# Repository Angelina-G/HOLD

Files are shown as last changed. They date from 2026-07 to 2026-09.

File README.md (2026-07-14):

# HOLD 工程仓库

## 项目简介
本仓库用于承载 HOLD 项目的嵌入式固件实验、整机联调、小程序前端壳子与阶段性开发记录。

当前重点包括：
- XIAO ESP32S3 多传感器固件验证
- MAX30102、MPU6050/MPU6500、压力模块、DRV2605L 的独立探针与整机冒烟测试
- 呼吸/心率相关原始数据采集与日志导出
- 微信小程序调试页与用户页壳子
- 接线文档、开发日志和阶段性方案沉淀

## 当前工程结构
- 固件主工程：PlatformIO + Arduino，板卡以 `seeed_xiao_esp32s3` 为主
- 传感器与算法公共头文件：`include/`
- 各独立实验入口与整机测试入口：`src/`
- 接线文档与方案说明：`docs/`
- 开发日志与阶段记录：`log/`
- 小程序与云函数：`web/`
- 串口采集与辅助脚本：`tools/`

## 当前实现范围
- 独立环境：MPU6050/MPU6500 探针、单 IMU 呼吸实验、MAX30102 指尖/胸口环境、DRV2605L LRA 环境、BLE 按键链路环境
- 整机环境：IMU + PPG + 压力 + DRV2605L + 热反馈 PWM + RGB 流水灯的统一冒烟测试
- 诊断能力：I2C 地址可见性、启动阶段日志、RGB 单色自检、兼容 `MPU6500/MPU9250` 系列 IMU 识别

## MR60BHA2 当前建议
- XIAO ESP32C6 + MR60BHA2 的首轮验证暂时改走 Arduino IDE 独立草图路径，避免继续受 PlatformIO 的 ESP32-C6 Arduino 环境问题阻塞。
- 可直接使用 [arduino/README.md](c:\Users\LBG\Desktop\hold\arduino\README.md) 中的验证步骤与草图。

## 推荐使用方式
1. 在 HOLD 根目录执行 pio run 进行编译。
2. 连接开发板后执行 pio run -t upload 进行烧录。
3. 执行 pio device monitor -b 115200 查看串口日志。

## 串口日志预期
- 上电或复位后会先输出一组启动信息。
- 随后每次 LED 翻转都会输出一行日志，包含运行毫秒数和当前 LED 状态。
- 如果打开监视器时没有看到启动日志，按一下开发板 Reset 键即可重新看到完整启动过程。

## 烧录异常排查
- 如果串口口号未出现，先更换数据线并重新插拔开发板。
- 如果上传失败，可按住 BOOT 键接入 USB 进入 BootLoader 模式后重新烧录。
- 如果点灯逻辑与观察结果相反，优先检查是否误用了外接 LED，而不是板载用户灯。

## 待确认项
- 当前仓库开发指南提到 Plus 版本，但本工程先按通用 XIAO ESP32S3 板卡配置建立。
- 若你的实际硬件为 XIAO ESP32S3 Plus，后续建议补充 Flash 容量与分区配置验证。

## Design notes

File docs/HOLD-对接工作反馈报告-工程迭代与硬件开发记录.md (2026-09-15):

# HOLD 对接工作反馈报告：工程迭代记录与硬件开发记录

## 摘要

本文档面向 HOLD 项目阶段性交接、科研汇报与后续工程复盘，整理 2026-05-22 至 2026-07-11 期间的主要 memory、debug、反馈、收获经验、疑难问题与可探索优化点。资料来源主要为仓库内 `log/`、`docs/`、`captures/` 与集成快照记录。

项目整体演进路线可以概括为：先完成 XIAO ESP32S3 主控与单传感器最小读数链路，再进入多传感器整机冒烟测试，随后打通 BLE 与微信小程序的用户侧控制闭环。硬件路线从 MAX30102、ICS43434、AD8232、薄膜压力、MPU6050/MPU6500、DRV2605L/LRA 与柔性热反馈等模块逐步展开，软件路线则围绕 PlatformIO 固件环境、串口诊断、VOFA 可视化、小程序 BLE 协议和数据闭环持续迭代。

当前阶段最重要的工程结论是：项目已具备多模块最小可运行能力和端到端 BLE 通信基础，但距离稳定、长期、可穿戴级产品仍有三类核心问题需要继续研究：生理信号质量与佩戴结构耦合、呼吸/心率算法的个体化稳健性、热/振动反馈的安全闭环与体感标定。

## 资料来源

本报告依据以下项目内记录归纳：

| 类别 | 代表文件 | 用途 |
|---|---|---|
| 主控与固件基础 | `log/firmware/2026-05-22-xiaoESP32S3点灯测试.md` | 验证主控烧录、串口、LED 心跳 |
| PPG | `log/max30102/raw-read/2026-05-23-MAX30102原始读取接入.md` | MAX30102 原始 Red/IR、FIFO、BPM 排查 |
| 麦克风 | `log/ics43434/raw-read/2026-05-25-ICS43434最小读取接入.md` | ICS43434 I2S 最小读取 |
| ECG | `log/ad8232/raw-read/2026-05-25-AD8232最小读取接入.md` | AD8232 模拟 ECG 最小链路 |
| 压力 | `log/pressure-film/raw-read/2026-05-25-薄膜压力模块最小读取接入.md` | 薄膜压力 AO 到 ADC 与 0-10 量化 |
| 传感路线 | `log/dev/2026-05-26/sensor-strategy/阶段性传感路线决策.md` | ECG、PPG、毫米波、位点策略 |
| ECG 布局 | `log/dev/2026-05-28/sensor-strategy/2026-05-28-近期传感与ECG布局讨论记录.md` | 胸带 ECG、三电极与两电极关系 |
| IMU 呼吸 | `log/firmware/2026-06-08-单IMU呼吸与运动状态实验.md` | 单 IMU 呼吸识别、个体化校准、VOFA 调试 |
| 触觉反馈 | `log/firmware/2026-06-11-DRV2605L独立LRA深呼吸震动环境.md` | DRV2605L + LRA RTP 呼吸包络 |
| 接线方案 | `docs/2026-06-18-完整小demo接线表.md` | 完整 Demo 引脚、总线、风险 |
| 整机测试 | `log/integration/2026-06-28-整机冒烟测试环境.md` | IMU、PPG、压力、DRV、热反馈、RGB 联调 |
| BLE 闭环 | `log/integration/2026-07-11-HOLD-integrated-BLE-miniapp-link.md` | BLE 通知、命令、小程序控制路径 |
| 小程序功能 | `docs/HOLD-miniapp-function-list.md` | 用户侧功能与调试页定位 |

## 一、项目阶段性脉络

### 1. 起步阶段：主控与最小反馈链路

项目初期采用 XIAO ESP32S3 / ESP32S3 Plus 作为主控平台，使用 PlatformIO + Arduino 进行固件开发。早期工作重点不是复杂算法，而是确认最小硬件链路：

- 主控可正常编译、烧录、复位。
- 串口日志可稳定输出。
- 板载 LED 或外接 LED 可作为运行心跳和阶段报码。
- 后续每个传感模块均以独立 reader 或独立 env 方式接入，避免在主循环中堆叠未验证逻辑。

这一阶段形成的经验是：嵌入式原型开发必须先确认“板子活着、串口活着、日志可见”，否则后续传感器问题会与供电、串口、烧录、引脚冲突混在一起。

### 2. 单传感器 bring-up 阶段

2026-05-23 至 2026-05-25 期间，项目依次完成 MAX30102、ICS43434、AD8232 与薄膜压力模块的最小接入。

此阶段采用的通用方法是：

- 每个模块先独立建立可观察输出。
- 先证明“能读到原始数据”，再考虑算法。
- 为初始化、寄存器访问、采样窗口、串口状态保留足够诊断字段。
- 对模拟输入先做窗口统计或量化，不直接进入复杂识别。

该策略有效避免了在硬件不确定时过早引入算法复杂度。

### 3. 传感路线收敛阶段

2026-05-26 至 2026-05-28 的路线评审将项目从“所有传感器等权推进”收敛为“ECG 主路线 + PPG/OHR 备路线 + 麦克风/压力辅助 + 毫米波中长期探索”。

关键判断包括：

- MAX30102 已证明 PPG 采样与基础 BPM 能力，但它更像手指/近指夹验证，不宜直接推演为后颈或挂颈式最终方案。
- AD8232 更适合作为当前 MVP 的节律主链路，因为 ECG 对 beat-to-beat、R-R、HRV 的工程价值更直接。
- 胸带 ECG 的难点主要在结构贴合、预紧、防滑和电极材料，而不是单纯“有没有第三个参考点”。
- 毫米波可作为呼吸、体动、存在感知的辅助或中长期路线，不宜直接替代 ECG 做 HRV 主链路。

### 4. 单 IMU 呼吸识别阶段

2026-06-06 至 2026-06-09，项目围绕 MPU6050/MPU6500 进行了单 IMU 胸口呼吸检测实验。该阶段是 debug 最密集的部分之一。

工程路线经历了多次转向：

1. 原始探针：确认 I2C 地址、WHO_AM_I、accel/gyro 可读。
2. 固定阈值呼吸识别：从重力投影、峰谷检测、运动门控开始。
3. 状态机排查：通过 `detected_peaks`、`detected_troughs`、`accepted_cycles`、`last_reject` 等诊断字段定位失败原因。
4. 个体化校准：从继续调固定阈值转向“引导式校准 + 个人参数”。
5. VOFA 可视化：输出呼吸载波、基线、滤波、斜率、阈值、拒绝原因等通道，直观看清波形。
6. 二级低通与最小反转摆幅：抑制高频毛刺导致的一口多记。

该阶段的核心经验是：当真实人体佩戴带来强个体差异时，继续堆全局阈值会陷入“漏检”和“误检”的反复摆动；更稳的路线是建立个人校准和可视化诊断。

### 5. 反馈器件与整机 Demo 阶段

2026-06-11 后，项目新增 DRV2605L + LRA 独立震动环境，并在 2026-06-18 形成完整小 Demo 接线表。2026-06-28 进一步形成整机冒烟测试环境，把 IMU、PPG、压力、DRV2605L、热反馈 PWM 和 RGB 状态灯整合到同一入口。

重要策略包括：

- IMU 与 PPG 共用主 I2C：D4(GPIO5) / D5(GPIO6)。
- DRV2605L 单独使用副 I2C：D6(GPIO43) / D7(GPIO44)。
- 压力模块 AO 接 D0/A0(GPIO1)，DO 暂不接。
- RGB 使用 D8/D9/D10，并保留板载 GPIO21 作系统状态。
- 热反馈只输出 MOSFET Gate 控制 PWM，不允许 GPIO 直接驱动加热片。

整机阶段发现并修复了一个典型嵌入式问题：`Serial.printf` 参数错位导致 Guru Meditation 崩溃。该问题表现为启动阶段似乎成功，但进入运行状态打印后重启。经验是，串口日志本身也可能成为崩溃源，格式化字符串必须与参数严格一致。

### 6. BLE 与小程序闭环阶段

2026-07-11，项目重点转向“硬件已连接但小程序无数据”“呼吸反馈命令无硬件响应”“校准无可见状态变化”等端到端问题。

最终形成的 BLE 闭环包括：

- 固件广播稳定 BLE 服务 `HOLD-INTEGRATED`。
- notify characteristic 带 BLE2902/CCCD。
- command characteristic 支持 write / write-no-response。
- 固件每 500ms 发 compact JSON telemetry。
- 小程序集中管理 UUID、解析 JSON/key-value/binary fallback。
- 首页成为用户控制面，调试页保留原始包和十六进制诊断。
- 命令覆盖 `breath_start`、`breath_stop`、`calibrate_start`，并能驱动 DRV2605 与状态字段变化。

此阶段的关键收获是：BLE 问题不能只看“是否连接成功”。完整链路必须同时满足服务发现、通知订阅、包格式可解析、命令写入、固件执行与状态回传。

## 二、工程迭代记录

### 1. 平台与工程组织迭代

项目采用 PlatformIO 多环境组织方式。每个独立实验入口均通过独立 env 或独立 `src/` 子目录隔离：

- `mpu6050_xiao_esp32s3_probe`
- `mpu6050_xiao_esp32s3_respiration`
- `drv2605l_xiao_esp32s3_lra_breath`
- `xiao_esp32s3_full_smoke_test`
- MAX30102 VOFA 与 BLE 按钮链路相关环境

这种组织方式的优点是：

- 单模块验证不干扰主线固件。
- 整机联调前可以保留独立回归入口。
- 同一硬件模块在不同阶段的引脚口径可以被明确记录。
- 出问题时可以回退到更小的验证环境。

需要注意的是，独立环境过多也会带来“接线口径分裂”。因此后续应维持一份唯一的整机引脚分配表，并明确哪些引脚只是独立实验临时口径。

### 2. 串口日志与诊断口径迭代

项目早期大量依赖串口日志完成 bring-up。日志从简单心跳逐步扩展为：

- I2C 扫描和地址可见性。
- 初始化阶段 `ok/miss/reason`。
- FIFO 指针、寄存器回读、错误计数。
- 传感器窗口统计。
- 呼吸状态机拒绝原因。
- VOFA 纯数值流。
- 整机状态单行汇总。
- BLE telemetry JSON。

这一过程表明，嵌入式项目中的“debug 输出”本身是工程资产，而不是临时噪声。它帮助团队从“感觉没反应”转向“知道卡在哪一层”。

### 3. 小程序工程迭代

小程序侧经历了从调试页、页面壳、首页控制面到 BLE 协议统一的过程。关键迭代点包括：

- 清理 sitemap 提示，避免开发者工具噪音干扰判断。
- 将首页定位为真实用户控制面。
- 将 debug 页定位为协议诊断面。
- 建立 `web/utils/ble-protocol.js`，统一 UUID、解析、字段归一化和中文标签。
- 支持原始通知包、解析后 metrics、连接状态、校准状态、呼吸引导状态展示。

经验是：用户界面和调试界面需要分层。把所有诊断内容塞进用户首页，会降低交互清晰度；但完全隐藏原始包，又会降低联调效率。

### 4. 数据导出与可视化迭代

项目在 IMU 呼吸和 MAX30102 阶段均使用 VOFA 或 CSV 作为关键观察工具：

- MPU6050 呼吸输出 23 列原始轴、滤波信号、状态机字段。
- MAX30102 手指/胸口实验输出 Red/IR、接触、滤波、幅值等字段。
- VOFA 用于确认“是否有主波”“毛刺在哪”“阈值是否与波形同量级”。

这说明当前项目已经从纯串口文本调试转向半结构化实验数据采集。后续若要偏科研，应进一步统一数据格式、实验标签、佩戴位点、动作条件与样本编号。

## 三、硬件开发记录

### 1. XIAO ESP32S3 主控

主控承担多传感器采样、反馈控制、BLE 广播与命令处理。已验证内容包括：

- PlatformIO 编译与烧录。
- USB 串口监视。
- 板载 LED 心跳。
- 多 I2C 与 ADC 混合使用。
- BLE 服务、通知与命令通道。

疑难点：

- 串口工具占用 COM 口会导致上传失败。
- ESP32S3 启动脚和板载 LED 逻辑需要避免误用。
- 整机联调时，日志格式错误可直接导致运行期崩溃。

### 2. MAX30102 PPG

开发目标从“能读到 Red/IR 原始值”逐步推进到“简单 BPM 与接触质量判断”。

主要成果：

- I2C 地址 0x57 和 Part ID 校验。
- FIFO 指针、配置寄存器、slot 配置与 rollover 诊断。
- 连续 Red/IR 原始样本输出。
- 基于 IR 的轻量心率估计。
- 窗口均值触点判断与 PBA 风格峰值检测。

主要 debug 记录：

- 初期出现 `part-id-read-failed`、`part_id=0x0`，需要 I2C 扫描和周期重扫。
- 后续出现 `reason=ok` 但 `wr_ptr=0 | rd_ptr=0 | avail=0`，说明通信成功但 FIFO 未产样本。
- 加入 slot 配置与关键寄存器回读后，FIFO 开始累计样本。
- `beats=0` 更像算法阈值和状态机问题，而不是硬件完全失效。
- 2Hz 串口输出只是显示频率，不等于传感器采样频率。

经验：

- PPG 调试不能只看设备识别，要同时看 FIFO 是否滚动、配置是否回读成功、接触均值是否稳定。
- 单点接触判断不可靠，窗口均值更稳。
- 从手指到胸口或其他位点时，PPG 的光机结构和贴合压力会显著改变信号质量。

### 3. ICS43434 数字麦克风

开发目标为 I2S 最小读取链路。

主要成果：

- 新增 I2S 引脚、采样率、DMA、批处理配置。
- 每 10ms 尝试读取样本批次，每 500ms 输出窗口统计。
- 输出 `min/max/p2p/mean` 等能量级字段。
- 实机确认 `seq`、`p2p`、`mean` 持续变化。

疑难点：

- 曾出现 `main.cpp` 被旧版本逻辑覆盖导致看不到麦克风信息。
- 第三方串口工具可能出现显示会话异常，PlatformIO 监视器确认固件实际输出。
- 声道选择、I2S 引脚丝印差异会造成数值异常弱或空读。

经验：

- 音频模块第一阶段只证明“有样本、有能量变化”即可，不应提前扩展声源识别。
- 若后续要做声音事件，应单独规划窗口、阈值、频域特征和隐私边界。

### 4. AD8232 ECG

开发目标为 OUTPUT 模拟量到 ADC 的最小链路，并为后续 R 峰和 HRV 做准备。

主要成果：

- OUTPUT 接 D1/A1/GPIO2。
- ADC 约 250Hz 轮询。
- 串口输出原始值和窗口统计。
- 支持 VOFA 单列原始 ADC 输出。
- 实机确认 raw/mean/max/p2p 持续变化。

疑难点：

- 当前读到变化不等于高质量 ECG。
- 多次出现 `min=0`，可能对应未贴附、接触不良、偏置不稳或噪声较大。
- LO+ / LO- 尚未纳入导联脱落判断。

经验：

- ECG 主线的真正难点在佩戴结构、电极接触和运动伪差。
- 凝胶电极适合作为研发基准件，不宜直接视为最终消费产品方案。
- 两电极适合产品化胸带，三电极更适合研发阶段稳定前端。

### 5. 薄膜压力模块

开发目标为 AO 模拟量读取并映射为 0-10 相对等级。

主要成果：

- AO 接 D0/A0/GPIO1。
- 启动时采集静置基线。
- 少量 ADC 采样平均后输出相对压力等级。
- 串口输出 `[pressure] N`，便于肉眼判断。

疑难点：

- 实机初期多为 `[pressure] 0`，更可能是未按压或模块未接入 AO，不代表代码失效。
- 不同模块 AO 动态范围可能不同，需要保留最小量程参数。

经验：

- 压力模块本阶段只使用 AO；DO 是比较器二值输出，不适合表达连续压力。
- 启动基线采集能避免空载偏置直接映射为非零等级。

### 6. MPU6050 / MPU6500 IMU

开发目标包括原始姿态/运动读取、呼吸节律估计和运动门控。

主要成果：

- I2C 探针确认模块在线。
- 兼容 MPU6050、MPU6500、MPU9250/9255 常见 WHO_AM_I。
- 输出加速度、角速度、pitch/roll、运动等级。
- 建立单 IMU 呼吸状态机和个体化校准。
- 接入 VOFA 调试流。

疑难点：

- 初期呼吸字段长期 `n/a`，原因不是完全无数据，而是重力投影和阈值过保守。
- 峰值计数快速增长而谷值不增长，说明状态机被高频扰动刷新。
- 时间窗过紧会让有效周期归零，过松又会导致一口多记。
- 累计平均周期显示会让用户误以为板载时钟不准。
- 校准阶段若只记录原始轴范围，会被姿态漂移拉高阈值。

经验：

- 呼吸识别必须区分“有没有主波”和“状态机是否正确接受主波”。
- 固定阈值难以覆盖不同佩戴方式和个体呼吸差异。
- 需要把运行期判定量与校准期学习量保持同一量纲。
- VOFA 曲线对定位高频毛刺、阈值失真和过早触发非常关键。

### 7. DRV2605L + LRA 震动反馈

开发目标为深呼吸式触觉引导。

主要成果：

- 独立 env 初始化 DRV2605L。
- 使用 LRA + RTP 实时播放模式。
- 输出吸气/呼气强到弱包络。
- 副 I2C D6/D7 独立于传感主总线。
- BLE 阶段命令可驱动 DRV2605 状态变化。

疑难点：

- 尚未根据具体 LRA 型号设置 rated voltage、overdrive clamp 和 auto-calibration。
- 体感强度、颗粒感、吸呼分辨度仍需人体确认。
- 震动可能通过机械耦合影响 PPG 或 IMU 信号。

经验：

- 触觉反馈应先独立验证体感，不要一开始并入传感状态机。
- DRV2605L 使用 RTP 更适合长呼吸节律包络，内置 ROM 效果更适合短脉冲。

### 8. 柔性热反馈

开发目标为热反馈控制脚与安全边界定义。

主要成果：

- 文档中补充柔性电加热片/发热膜。
- 整机冒烟环境中加入热反馈 PWM 控制脚。
- 上电先拉低，延迟 5 秒后再输出 80% PWM，便于观察启动阶段。
- 明确必须使用逻辑级 N-MOSFET 控制外部电源。

疑难点：

- 当前缺少加热片额定参数。
- 尚未建立温度采样、限温保护、安全时长和热舒适度闭环。

经验：

- GPIO 不能直接驱动加热片。
- 开环 PWM 只能作为控制脚验证，不宜作为长期功能。

### 9. RGB 状态灯

开发目标为整机阶段可视化状态反馈。

主要成果：

- RGB 共阴极接 D8/D9/D10。
- 启动阶段加入 R/G/B 单色自检。
- 板载 GPIO21 保留为系统状态灯。

疑难点：

- 外接 RGB 与板载 LED 的有效电平逻辑不同。
- 若蓝色不亮，应优先查 GPIO9、限流电阻、极性和共阴极接法。

经验：

- RGB 是低成本但高价值的现场诊断工具，可用于无串口场景下判断固件阶段。

## 四、关键疑难点与排查过程

### 1. MAX30102：设备识别、FIFO 与算法三层问题混杂

现象包括 Part ID 失败、FIFO 不滚动、`beats=0`、BPM 显示停滞。

排查路径：

1. 用 I2C 扫描确认地址是否可见。
2. 用 Part ID 与关键寄存器回读确认通信层是否稳定。
3. 用 FIFO 指针确认是否真的有样本。
4. 用 Red/IR 原始值确认光学通道是否变化。
5. 用窗口均值确认接触质量。
6. 最后才调峰值检测和 BPM 状态机。

收获：

- 同一个“没有心率”的表现可能来自硬件、寄存器配置、FIFO、接触、算法任一层。
- 必须保留跨层诊断字段，否则容易误判。

### 2. IMU 呼吸：固定阈值陷入反复调参

现象包括正常呼吸难触发、剧烈运动反而触发、深呼吸一口多记、有效周期漂移。

排查路径：

1. 增加峰/谷计数和拒绝原因。
2. 区分半周期过短、整周期不合格、振幅太低和运动门控。
3. 修复极值时间反复刷新的状态机问题。
4. 拆分最近一次周期和历史平均周期显示。
5. 引入个体化校准。
6. 接入 VOFA 观察真实波形和毛刺。
7. 加入最小反转摆幅和检测专用二级低通。

收获：

- 人体佩戴下的呼吸信号不是理想正弦。
- 阈值不能只根据想象调整，必须回到曲线和拒绝分布。
- 个体化校准不是额外复杂度，而是减少全局阈值反复拉扯的必要步骤。

### 3. BLE：连接成功不等于协议闭环成功

现象包括小程序已连接但无数据、收到无法解析通知、按钮命令无硬件响应、校准无可见变化。

排查路径：

1. 确认固件广播稳定 service。
2. 确认 notify characteristic 带 BLE2902/CCCD。
3. 确认小程序订阅通知成功。
4. 统一固件上报格式为 JSON telemetry。
5. 统一小程序协议解析。
6. 增加 command characteristic，并让固件把命令转为 DRV2605 与状态字段变化。

收获：

- BLE 链路至少包含发现、订阅、解析、写入、执行、回传六个环节。
- 首页和 debug 页应共用协议层，避免两个页面各自实现导致行为不一致。

### 4. 整机冒烟：启动成功后运行期崩溃

现象为 setup 阶段完成、加热使能后不久自动重启。

排查结论：

- 不是单纯加热负载或 I2C 卡死，而是一处整机状态行 `Serial.printf` 参数错位触发 Guru Meditation。

收获：

- 串口诊断代码也属于运行逻辑，必须编译和实机验证。
- 冒烟测试应包含 boot 分段日志，帮助区分初始化失败和运行期崩溃。

### 5. 热反馈：控制脚验证与安全功能不能混为一谈

现象与边界：

- 整机工程目前只验证 PWM 控制脚。
- 尚未拿到加热片额定参数。
- 无温度闭环、限温、超时和热舒适度评价。

收获：

- 热反馈必须作为高风险反馈通道处理。
- 没有闭环前，不应把 80% PWM 理解为可长期使用的功能参数。

## 五、阶段性反馈与科研化归纳

### 1. 工程方法论反馈

本项目最有效的方法不是一次性搭完整系统，而是“最小链路 -> 诊断可见 -> 单模块收口 -> 整机冒烟 -> 端到端闭环”。该方法尤其适用于多传感器可穿戴原型，因为硬件、佩戴、算法和交互之间高度耦合。

科研化表达可归纳为：

- 对每个传感器建立独立观测通道，降低变量耦合。
- 以原始数据可获取性作为第一验收标准。
- 以可解释中间变量作为算法迭代依据。
- 以整机冒烟测试验证模块间的供电、总线和状态交互。
- 以 BLE 与小程序闭环验证系统级可用性。

### 2. 硬件路线反馈

当前硬件路线已覆盖生理、行为、反馈三层：

- 生理层：ECG、PPG、IMU 呼吸。
- 行为/环境辅助层：压力、麦克风、运动等级。
- 反馈层：LRA 震动、RGB、热反馈。

但下一阶段应避免继续横向扩传感器数量，优先提升现有主链路质量。建议按优先级聚焦：

1. AD8232 ECG：R 峰、R-R、短窗 HRV、导联稳定性。
2. IMU 呼吸：个体化校准、有效周期、叹气/深呼吸事件。
3. DRV2605L：体感包络、强度标定、反馈与检测互扰。
4. BLE 小程序：稳定控制、状态回传、数据记录。
5. 热反馈：只有在温控安全方案明确后再进入长期功能。

### 3. 算法路线反馈

当前算法迭代已经显示，简单阈值法可用于最小验证，但难以支撑稳定人体佩戴。

建议后续算法分层：

- 信号质量层：接触、运动、噪声、漂移、饱和。
- 基础事件层：心跳、呼吸峰谷、压力变化、动作强度。
- 个体化参数层：用户基线、呼吸节律、ECG 波形幅度、佩戴位点。
- 状态融合层：焦虑相关趋势或引导触发，不直接承诺医学诊断。

### 4. 交互与产品路线反馈

小程序已从调试工具转向用户控制面，但仍处于工程验证阶段。后续建议：

- 首页只放用户真正需要的控制和状态。
- debug 页保留原始 BLE 包、hex、协议字段和错误码。
- 将校准过程做成明确步骤，而不是仅依赖串口提示。
- 将呼吸引导、震动反馈和校准结果联动展示。

## 六、可探索优化点

### 1. 数据与实验规范

建议建立统一实验数据模板：

- 受试者编号或匿名代号。
- 佩戴位点。
- 传感器型号和接线版本。
- 固件 env 和 commit。
- 工况标签：静坐、说话、走动、深呼吸、叹气、按压、反馈开启。
- 原始数据字段说明。
- 观察结论和异常标记。

这将把当前“工程日志”进一步升级为可复现实验记录。

### 2. ECG 主链路

可探索方向：

- 加入 LO+ / LO- 导联脱落状态。
- 输出原始 ECG 与轻滤波 ECG 双通道。
- 实现 R 峰检测、BPM、R-R 间期。
- 比较横向胸带布局和类 Lead II 斜向布局。
- 对比凝胶电极、导电织物、金属干电极、导电硅胶。
- 记录静坐、说话、走动、深呼吸下的波形可用性。

### 3. PPG/OHR 备路线

可探索方向：

- 保留 MAX30102 作为 PPG 数据能力验证和对照。
- 不再将 MAX30102 后颈化作为主路线。
- 若重启光学路线，优先明确耳部、太阳穴、上臂或腕部位点。
- 评估绿光主导或集成多波长 wearable OHR 模组。
- 把遮光、压紧、air gap、串扰纳入结构设计，而不是只调固件。

### 4. IMU 呼吸

可探索方向：

- 将个人 profile 持久化到 Flash/NVS。
- 增加轻微活动干扰段校准。
- 继续保留 VOFA 输出，用曲线验证二级低通与反转摆幅。
- 在统计阈值之上尝试逻辑回归或小决策树。
- 与毫米波呼吸或 ECG 呼吸性调制做可信度互补。

### 5. 反馈闭环

可探索方向：

- DRV2605L 针对具体 LRA 做 auto-calibration。
- 建立触感主观评分表：强度、节律、舒适度、可分辨度、打扰程度。
- 研究震动对 IMU/PPG 的机械干扰。
- 热反馈加入温度传感、限温、超时、软启动和异常断开。

### 6. BLE 与小程序

可探索方向：

- 将 telemetry schema 固化成版本化协议。
- 为每条命令加入 ack、错误码和状态机。
- 小程序侧记录连接、订阅、命令、通知的时间线。
- 支持导出 CSV/JSON 实验包。
- 手机端完成校准引导，减少对串口的依赖。

## 七、当前未解决问题清单

| 问题 | 当前状态 | 建议优先级 |
|---|---|---:|
| ECG 原始波形质量与 R 峰识别 | 已有 ADC/VOFA 基础，未完成算法闭环 | 高 |
| IMU 呼吸个体化校准稳定性 | 已有 V1 与 VOFA，需实测收敛 | 高 |
| BLE 手机端完整实机验证 | PC BLE 已验证，小程序手机端仍需持续测 | 高 |
| LRA 体感强度与舒适度 | 命令路径已通，主观体验未定量 | 中 |
| 热反馈安全闭环 | 仅控制脚验证，缺温度闭环 | 高 |
| PPG 胸口/非手指位点可用性 | 已做胸口首轮，仍需结构与算法验证 | 中 |
| 麦克风声音事件 | 只完成样本读取，未做事件识别 | 低 |
| 压力模块真实量程 | 已有 0-10 相对等级，需实物按压标定 | 中 |
| 整机供电与地线抗扰 | 冒烟通过，长期稳定未验证 | 高 |

## 八、交接建议

下一位对接工程师或研究成员建议按以下顺序接手：

1. 先阅读 `docs/2026-06-18-完整小demo接线表.md`，按唯一整机接线口径搭硬件。
2. 烧录 `xiao_esp32s3_full_smoke_test`，确认 IMU、PPG、压力、DRV2605L、RGB、热反馈控制脚的 boot 与 runtime 状态。
3. 用 BLE 小程序连接 `HOLD-INTEGRATED`，验证 telemetry、`calibrate_start`、`breath_start`、`breath_stop`。
4. 若目标是生理指标，优先回到 AD8232 ECG 独立链路，补 R 峰/R-R，而不是继续扩新传感器。
5. 若目标是呼吸引导，优先继续 IMU 个体化校准和 LRA 体感标定。
6. 热反馈只允许在安全闭环设计完成后进入长时间人体测试。

## 九、结论

HOLD 项目当前已从“单点硬件试验”推进到“多传感器整机 + BLE 小程序控制”的阶段。项目的主要价值不只在于某个传感器已经能读数，而在于形成了一套较完整的原型研究方法：单模块最小验证、详细串口诊断、可视化数据流、阶段性路线评审、整机冒烟测试和端到端交互闭环。

后续最值得投入的方向不是继续增加模块数量，而是把主链路做深：以 ECG 或个体化 IMU 呼吸为核心，建立可重复采集、可解释诊断、可量化反馈和可安全佩戴的验证体系。只有当信号质量、佩戴结构、反馈安全和数据记录四件事同时闭环后，项目才真正从工程 Demo 进入可研究、可评估、可迭代的科研原型阶段。

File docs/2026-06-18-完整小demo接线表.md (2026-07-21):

# 完整小 Demo 接线表

## 1. 目标模块范围

本接线表面向当前准备组装的完整小 Demo，纳入以下模块：

1. MPU6050 IMU
2. MAX30102 PPG
3. DRV2605L + LRA 震动模块
4. RGB 共阴极三色 LED
5. 薄膜压力传感器模块（AO / DO / VCC / GND）

本表不包含当前仓库里的 AD8232 ECG 和 ICS43434 麦克风，因为你这轮明确要先整合的是 IMU、PPG、震动、RGB、压力。

## 2. 先说结论

建议整机版采用如下总线与引脚策略：

1. IMU、PPG 共用主 I2C：
   - SDA: D4 / GPIO5
   - SCL: D5 / GPIO6
2. 当前实机将 DRV2605L 与传感器并到主 I2C：
   - SDA: D4 / GPIO5
   - SCL: D5 / GPIO6
   - D6 / GPIO43、D7 / GPIO44 保留为排障时的可选副 I2C
3. RGB 共阴极三色 LED 使用 3 个独立 GPIO：
   - R: D8 / GPIO7
   - G: D9 / GPIO8
   - B: D10 / GPIO9
4. 薄膜压力模块使用模拟输出 AO：
   - AO -> D0 / A0 / GPIO1
   - DO 本轮不接

这样接的理由是：

1. 三个模块地址不冲突，当前实机用一组主 I2C 减少线束；固件仍兼容 DRV2605L 使用副 I2C。
2. 压力模拟输入和 I2C / RGB 不冲突。
3. RGB 选用 D8-D10 后，不会占用当前主线已经确定的 I2C 和 ADC。
4. 不使用 GPIO0，避免碰启动绑带脚。
5. 不占用板载用户灯 GPIO21，避免和现有系统状态灯逻辑混淆。

## 3. 现有代码里的真实占用情况

### 3.1 主线/共享配置里的既有口径

根据 [include/project_config.h](include/project_config.h)：

1. 共享 I2C：
   - SDA = GPIO5
   - SCL = GPIO6
2. 压力模块模拟输入：
   - GPIO1
3. 板载用户灯：
   - GPIO21

### 3.2 独立实验环境里的特殊口径

当前仓库里有几个独立实验入口，为了单独验证模块，曾经故意用了不同接线：

1. IMU 呼吸实验 [src/mpu6050_xiao_esp32s3_respiration/main.cpp](src/mpu6050_xiao_esp32s3_respiration/main.cpp)
   - I2C: D4(GPIO5) / D5(GPIO6)

2. MAX30102 独立 VOFA 环境 [src/max30102_xiao_esp32s3_vofa/main.cpp](src/max30102_xiao_esp32s3_vofa/main.cpp)
   - I2C: D2(GPIO3) / D3(GPIO4)
   - 这是独立展示环境的临时口径，不是必须保留到整机版

3. DRV2605L 独立 LRA 环境 [src/drv2605l_xiao_esp32s3_lra_breath/main.cpp](src/drv2605l_xiao_esp32s3_lra_breath/main.cpp)
   - I2C: D6(GPIO43) / D7(GPIO44)
   - 这是为了在独立实验时完全避开 IMU / PPG 线路，不代表整机版必须单独占一组 I2C

## 4. 冲突判断与最终调整

### 4.1 IMU / PPG / DRV2605L 是否冲突

结论：

1. 引脚层面，如果保留各自独立实验口径，不冲突。
2. 总线层面，这三个模块理论上可以并到同一组 I2C 上。

原因：

1. MPU6050 常用地址为 `0x68` 或 `0x69`
2. MAX30102 地址为 `0x57`
3. DRV2605L 常用地址为 `0x5A`

但整机版这次不建议让三者都硬并到一组 I2C。原因不是地址冲突，也不是单纯带宽不够，而是：

1. DRV2605L 对应主动震动输出链路，确实可能带来供电和机械扰动。
2. 当前实机优先减少线束脱落风险，因此三块模块共享主 I2C。
3. 若共享总线出现震动相关故障，再把 DRV2605L 移到副 I2C 做隔离排查。

因此当前整机版建议是：

1. 主 I2C：IMU + PPG + DRV2605L
2. 副 I2C：只在总线排障时给 DRV2605L 使用

主 I2C 接法：

1. SDA = D4 / GPIO5
2. SCL = D5 / GPIO6

可选副 I2C 接法：

1. SDA = D6 / GPIO43
2. SCL = D7 / GPIO44

### 4.2 压力模块是否冲突

结论：不冲突。

理由：

1. 当前工程已经把压力模块 AO 口定义在 D0/A0(GPIO1)。
2. 这个引脚不与 I2C、板载 LED、当前推荐 RGB 引脚重叠。
3. 模块的 DO 是比较器数字输出，本轮你要的是模拟压力数据，因此不需要接。

### 4.3 RGB 共阴极三色 LED 是否冲突

结论：建议使用 D8 / D9 / D10，不与本轮完整 Demo 目标模块冲突。

理由：

1. D8(GPIO7)、D9(GPIO8)、D10(GPIO9) 当前不被 IMU / PPG / DRV / 压力使用。
2. 这三个脚连续，布线和代码定义都更清晰。
3. 避开了 GPIO0 启动脚和 GPIO21 板载灯。

注意：

1. 如果你后面又想把 ICS43434 麦克风并进来，那么 D8-D10 会和麦克风 I2S 冲突。
2. 但按你本轮目标，麦克风不在整合范围内，所以当前这样分配最合适。

## 5. 推荐整机版接线总表

### 5.1 电源与地

所有模块必须共地。

建议：

1. XIAO 3V3 -> MPU6050 VCC
2. XIAO 3V3 -> MAX30102 VIN
3. XIAO 3V3 -> DRV2605L VIN
4. XIAO 3V3 -> 薄膜压力模块 VCC
5. XIAO GND -> MPU6050 GND
6. XIAO GND -> MAX30102 GND
7. XIAO GND -> DRV2605L GND
8. XIAO GND -> 薄膜压力模块 GND
9. XIAO GND -> RGB LED 共阴极公共脚

### 5.2 I2C 总线

主 I2C 接法：

1. XIAO D4(GPIO5) -> MPU6050 SDA + MAX30102 SDA + DRV2605L SDA
2. XIAO D5(GPIO6) -> MPU6050 SCL + MAX30102 SCL + DRV2605L SCL

说明：

1. 这是标准 I2C 并联接法，不是串联。
2. MPU6050、MAX30102 与 DRV2605L 共享该总线，地址分别为 `0x68`、`0x57`、`0x5A`。
3. 固件启动时会扫描 D4/D5 与 D6/D7，并自动选择可见的总线。

### 5.3 MPU6050

建议接法：

1. 3V3 -> VCC
2. GND -> GND
3. D4(GPIO5) -> SDA
4. D5(GPIO6) -> SCL
5. AD0/ADO -> GND
6. INT/XDA/XCL 本轮不接

说明：

1. AD0 接地时通常地址为 `0x68`。
2. 若你实物板上 AD0 被拉高，则地址会变成 `0x69`，代码仍可兼容探测，但接地更统一。

### 5.4 MAX30102

建议接法：

1. 3V3 -> VIN
2. GND -> GND
3. D4(GPIO5) -> SDA
4. D5(GPIO6) -> SCL
5. INT 本轮先不接

说明：

1. 虽然独立 VOFA 环境曾经用过 D2/D3，但整机版不建议继续保留那套独立接法。
2. 整机版建议直接并回共享 I2C，减少线束和代码口径分裂。

### 5.5 DRV2605L + LRA

建议接法：

1. 3V3 -> DRV2605L VIN
2. GND -> DRV2605L GND
3. D4(GPIO5) -> DRV2605L SDA
4. D5(GPIO6) -> DRV2605L SCL
5. DRV2605L OUT+ -> LRA 正极
6. DRV2605L OUT- -> LRA 负极

说明：

1. 当前实机采用共享 D4/D5，减少容易脱落的线束。
2. 若震动造成总线或 PPG 干扰，可把 DRV2605L 的 SDA/SCL 改接 D6/D7，固件无需修改。

### 5.6 薄膜压力模块

假设模块引脚为 `A0 / D0 / GND / VCC`，本轮只接模拟量：

1. VCC -> 3V3
2. GND -> GND
3. A0 -> XIAO D0 / A0 / GPIO1
4. D0 -> 不接

说明：

1. 你要的是“传递压感模拟数据”，所以必须用 A0，不建议本轮接 D0 作为主输入。
2. D0 通常只是阈值比较后的二值输出，不适合表达连续压力变化。

### 5.7 RGB 共阴极三色 LED

推荐接法：

1. 共阴极公共脚 -> GND
2. 红色阳极 -> 串联限流电阻 -> XIAO D8 / GPIO7
3. 绿色阳极 -> 串联限流电阻 -> XIAO D9 / GPIO8
4. 蓝色阳极 -> 串联限流电阻 -> XIAO D10 / GPIO9

限流建议：

1. 每个颜色都要单独串一个电阻，不允许三个颜色共用一个电阻。
2. 建议首轮使用 `220R` 到 `1k`。
3. 如果只需要状态提示、亮度不必很高，`330R` 或 `470R` 更稳妥。

共阴极逻辑说明：

1. GPIO 输出高电平时，该颜色导通点亮。
2. GPIO 输出低电平时，该颜色熄灭。
3. 这和当前板载用户灯 GPIO21 的低电平点亮逻辑不同，不要混淆。

## 6. 最终推荐引脚占用一览

| 功能 | XIAO 引脚 | GPIO | 去向 |
|---|---|---:|---|
| 功能 | XIAO 引脚 | GPIO | 去向 |
|---|---|---:|---|
| 主 I2C SDA | D4 | 5 | MPU6050 SDA + MAX30102 SDA + DRV2605L SDA |
| 主 I2C SCL | D5 | 6 | MPU6050 SCL + MAX30102 SCL + DRV2605L SCL |
| 可选副 I2C SDA | D6 | 43 | 排障时接 DRV2605L SDA |
| 可选副 I2C SCL | D7 | 44 | 排障时接 DRV2605L SCL |
| 压力模拟输入 | D0 / A0 | 1 | 薄膜压力模块 A0 |
| RGB 红 | D8 | 7 | RGB LED 红色阳极（串电阻） |
| RGB 绿 | D9 | 8 | RGB LED 绿色阳极（串电阻） |
| RGB 蓝 | D10 | 9 | RGB LED 蓝色阳极（串电阻） |
| 板载用户灯 | 板载 | 21 | 保留给系统状态，不外接 |

## 7. 保留和空闲引脚

按当前方案，以下引脚仍空闲：

1. D1 / A1 / GPIO2
2. D2 / GPIO3
3. D3 / GPIO4

这意味着：

1. 若后面你又要接数字中断、按键或备用状态灯，还有余量。
2. 后续若还要加按键、中断线或额外状态灯，仍有扩展余量。

## 8. 重要注意事项

### 8.1 关于 I2C 上拉

IMU、MAX30102、DRV2605L 模块板上常常自带上拉电阻。

因此：

1. 可以先直接并线验证。
2. 若后面发现波形不稳、通信偶发失败，再排查总线上拉是否过重。

### 8.2 关于供电能力

1. MAX30102、MPU6050、DRV2605L、压力模块都挂在 3V3 上时，首轮小 Demo 一般可行。
2. 但 LRA 震动时会带来瞬时电流扰动，若出现 PPG 明显受干扰，后续要重点看供电和地线布局。

### 8.3 关于 RGB LED

1. 一定要串联限流电阻。
2. 不要直接把 LED 阳极硬接 GPIO。

### 8.4 关于压力模块

1. 本轮只用 A0。
2. D0 暂不接，避免把比较器输出误当成连续压力数据。

## 9. 本轮最终建议

如果你现在就开始搭完整 Demo，建议直接按这版接：

1. IMU、PPG、DRV2605L 共用 D4/D5 主 I2C
2. D6/D7 仅保留为 DRV2605L 的可选排障总线
3. 压力模块 A0 接 D0/A0(GPIO1)
4. RGB 共阴极 LED 接 D8/D9/D10，并各自串电阻

这是当前在“尽量不冲突、便于排障、同时贴近现有独立实验代码口径”三点之间最平衡的一版。

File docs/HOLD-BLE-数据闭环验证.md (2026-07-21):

# HOLD BLE 数据闭环验证

## 当前集成环境

- 固件环境：`xiao_esp32s3_full_smoke_test`
- 小程序目录：`web/`
- 主 I2C：D4 / GPIO5 为 SDA，D5 / GPIO6 为 SCL
- 预期地址：MAX30102 `0x57`、MPU6500 `0x68`、DRV2605L `0x5A`

## 遥测字段

固件通过 BLE 通知发送 `t=tel` JSON。关键字段如下：

| 字段 | 含义 | 有效条件 |
| --- | --- | --- |
| `hr` | 心率 bpm | `pp=1`、`ct=1`，范围 35 到 220 |
| `br` | 呼吸率 次/分 | 范围 6 到 45，并满足来源条件；不依赖综合 `wear` 位 |
| `bs` | 呼吸来源 | `imu`、`pressure` 或 `none` |
| `bd` | IMU 呼吸判定阶段 | `warmup`、`motion`、`cycle`、`confirm`、`valid` |
| `bx` / `bn` / `ba` | 候选呼吸率 / 连续周期数 / 个体阈值 | 用于定位呼吸为何尚未有效，不参与健康结论 |
| `mr` / `mo` | IMU 就绪 / 运动状态 | 比较窗口只接受 `mr=1` 且 `mo=still` |
| `pp` / `ir` / `red` | PPG 就绪 / 原始红外 / 红光 | 原始值只用于波形和接触判断 |
| `ps` / `pr` / `pl` | 压力就绪 / 原始值 / 等级 | 压力来源呼吸要求 `ps=1` 且 `pr` 有限 |
| `sessionId` | 小程序连接会话 | 引导事件和前后样本必须完全一致 |

`bs=imu` 时呼吸有效性依赖 `mr=1`；`bs=pressure` 时依赖 `ps=1`。`bs=none`、缺失或未知来源一律无效。综合 `wear` 可能受 PPG/压力贴合状态影响，不能反向否决已经由对应来源确认的呼吸率。不得把两个来源混在同一次前后比较中。

IMU 首次用 3 秒窗口选择呼吸变化最大的轴。若 12 秒仍没有形成候选周期，固件会重新学习轴，避免佩戴动作让算法永久锁在错误方向；重学期间 `bd` 会回到 `warmup`，不是断连。

## 前后对比准入

综合变化分数只在以下条件全部满足时显示：

1. `breath_start`、`breath_stop` 和遥测样本属于同一个非空 `sessionId`。
2. 引导前后各有至少 24 秒有效静止覆盖；引导后从第一个有效目标指标样本开始取窗。
3. 两个窗口的心率均有效。
4. 两个窗口的呼吸均有效，且来自同一个 `bs`。
5. 每个窗口至少 8 条有效样本，且有效样本覆盖满足同一门槛。

若只有心率或呼吸一项满足前后窗口，界面只显示该单指标的方向，不生成综合分数。两项均不足时显示原因，也不使用旧报告或历史占位数据补齐。引导前使用中性基线色；引导后暖色表示指标上升方向，青绿冷色表示下降方向，并直接显示有效指标差值。该结果仅表示本次变化趋势，不是焦虑诊断或医学诊断。

## 用户测试闭环

首页“开始一次舒缓测试”进入专用流程：

1. 确认 BLE 命令特征、实时遥测、PPG 接触和静止状态。
2. 用户填写引导前紧张感，记录 30 秒稳定基线。
3. 执行 60 秒呼吸引导；震动增强对应吸气，减弱对应呼气，用户可提前停止。
4. 引导结束后继续记录 30 秒恢复数据，再填写引导后紧张感。
5. 主观变化始终单独展示；生理趋势只采用本次同一 BLE 会话的有效数据。

断开 BLE 不会自动生成记录，恢复数据不足也不会回退到上一条报告。

## 验证命令

```powershell
$env:PLATFORMIO_CORE_DIR='D:\Desktop\HOLD-main\.platformio'
pio run -e xiao_esp32s3_full_smoke_test
pio run -e xiao_esp32s3_full_smoke_test -t upload --upload-port COM13
node web/tests/ble-notify-smoke.js
node web/tests/health-comparison-smoke.js
python tools/serial/verify_integrated_stream.py --self-test
```

复位后串口必须看到：

```text
[self-test] imu-respiration=PASS
[smoke][i2c-scan] D4/D5 primary ... found=0x57,0x5A,0x68
[smoke] init ... imu=OK | ppg=OK | pressure=OK | motor=OK
```

真人验证时先稳定佩戴且不启动震动。调试页的 `bd` 应依次经过 `warmup/cycle/confirm/valid`，随后出现 `br=6..45` 和 `bs=imu` 或 `bs=pressure`；若显示 `motion`，需保持设备稳定。连接后退出调试页，缓存序号仍应持续增长。完成一次引导后继续静止佩戴，系统从首个有效心率与呼吸样本开始形成后测窗口，首页、当日分析、历史与报告应显示同一次会话的实时波形及前后比较。

佩戴验收时关闭微信蓝牙连接后运行以下命令；打开串口会重启开发板，因此需在命令开始后立即稳定佩戴：

```powershell
python tools/serial/verify_integrated_stream.py --port COM13 --duration 90 --require-vitals
```

只有 `i2c`、`imu`、`ppg`、`pressure`、`haptic`、`heart` 和 `breath` 全部显示 `PASS`，才算板端真实数据验收完成。

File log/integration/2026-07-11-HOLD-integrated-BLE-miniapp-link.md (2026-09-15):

# 2026-07-11 HOLD integrated BLE miniapp link

## Goal

- Fix miniapp connected-but-no-data.
- Fix breath feedback command having no hardware response.
- Fix calibration having no visible state change.
- Keep homepage as the user-facing control surface and debug page as diagnosis only.

## First principles diagnosis

The working chain must have all four links:

1. Hardware advertises a stable BLE service.
2. Miniapp discovers the service and subscribes to a notify characteristic with CCCD.
3. Hardware emits parseable packets on notify.
4. Miniapp writes commands to a writable command characteristic, and firmware turns those commands into DRV2605 state.

The screenshot symptom "收到无法解析的通知" showed link 2 was partly alive, but link 3 and link 4 were not an agreed protocol. Previous iterations also emphasized BLE2902/CCCD and direct miniapp-to-hardware BLE first, before cloud.

## Changes

- `src/xiao_esp32s3_full_smoke_test/main.cpp`
  - Added BLE service `19b10010-e8f2-537e-4f6c-d104768a1214`.
  - Added notify characteristic `19b10011-e8f2-537e-4f6c-d104768a1214` with `BLE2902`.
  - Added command characteristic `19b10013-e8f2-537e-4f6c-d104768a1214` with write and write-no-response.
  - Emits compact JSON telemetry every 500 ms: type, device id, heart, beat, motion, phase, IMU model, haptic, breath, calibration.
  - Handles `breath_start`, `breath_stop`, `calibrate_start`.
  - Breath mode drives DRV2605 RTP with a rising/falling envelope.
  - Calibration mode pulses DRV2605 and reports `calibration_started` / `calibration_done`.
  - Fixed calibration race: start time is written before `calibrationRunning=true`.

- `web/utils/ble-protocol.js`
  - Centralized BLE UUIDs.
  - Parses JSON, key-value text, and binary fallback packets.
  - Normalizes short firmware fields (`br/hr/bt/mo/ph/hp/bg/cg`) to miniapp fields.
  - Adds Chinese labels for motion and guidance phase.

- `web/pages/home/*`
  - Homepage now performs real BLE scan/connect/subscribe/write.
  - Homepage shows connection, calibration, breath guidance, live metrics, raw packet summary.
  - Main controls: scan/connect, disconnect, clear cache, breath guide, base calibration.

- `web/pages/index/*`
  - Debug page now shares the same BLE protocol and command path.
  - Keeps raw/hex diagnostics for protocol inspection.

## Verification

- Backed up workspace to `D:\Desktop\HOLD-main\backup-20260711-114424`.
- Built firmware:
  - `python -m platformio run -e xiao_esp32s3_full_smoke_test`
  - Result: success.
- Uploaded firmware to USB serial `COM13`.
  - Board: ESP32-S3, MAC `e0:72:a1:fa:0f:5c`.
  - Result: success.
- Serial boot check:
  - IMU `MPU6500` OK.
  - MAX30102 OK.
  - Pressure sensor OK.
  - DRV2605 OK.
  - BLE advertising `HOLD-INTEGRATED`.
- PC BLE scan:
  - Found `HOLD-INTEGRATED`.
  - Service UUID present.
- PC BLE connect/notify/write:
  - Received telemetry JSON.
  - `calibrate_start` produced `calibration_started`, `cg=1`, `ph=calibrating`.
  - `breath_start` produced `breath_started`, `bg=1`, `ph=inhale`.
  - `breath_stop` produced `breath_stopped`, `bg=0`, `ph=idle`.
- Miniapp JS checks:
  - `node --check web/utils/ble-protocol.js`
  - `node --check web/pages/home/index.js`
  - `node --check web/pages/index/index.js`
  - Result: success.

## Remaining risk

- Respiration BPM is currently `0` in the integrated smoke firmware because the production respiration estimator is not yet merged into this entrypoint.
- Physical vibration amplitude was verified by command/state path and DRV2605 RTP writes, but tactile strength still needs human confirmation on the worn prototype.
- WeChat DevTools is open for phone-side testing; PC BLE already validated the underlying BLE protocol.

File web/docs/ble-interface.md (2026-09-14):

# HOLD 小程序 ↔ 硬件 BLE 接口文档

> 本文档基于小程序端代码（`utils/ble-debug-protocol.js`、`utils/hold-ble-runtime.js`）逆向整理，描述微信小程序与 HOLD-INTEGRATED 设备之间的 BLE 通信协议。
> 整理日期：2026-09-06 ｜ 协议版本：runtime state v2

---

## 1. 概览

| 项 | 说明 |
|---|---|
| 传输方式 | BLE GATT，单服务双特征（Notify + Write） |
| 数据编码 | **JSON 文本**，逐字节 ASCII/UTF-8 解码，单条通知即一个完整 JSON 对象 |
| 下行（设备 → 小程序） | Notify 特征推送，共 8 类报文 + 2 类日志报文 |
| 上行（小程序 → 设备） | Write 特征写入 JSON 命令，目前 2 条 |
| 设备识别 | 广播名包含关键字 `HOLD-INTEGRATED`（大小写不敏感） |
| 连接超时 | 10 秒 |
| 重连策略 | 意外断开后 1.2 秒触发重扫重连，最多 3 次；手动断开不触发 |

---

## 2. GATT 结构

| 角色 | UUID | 属性 |
|---|---|---|
| Service | `19b10010-e8f2-537e-4f6c-d104768a1214` | — |
| Notify Characteristic | `19b10011-e8f2-537e-4f6c-d104768a1214` | Notify |
| Write Characteristic | `19b10012-e8f2-537e-4f6c-d104768a1214` | Write / WriteNoResponse |

**特征兜底匹配规则**：若精确 UUID 未匹配到，小程序会退化为按属性查找——Notify 特征取第一个 `properties.notify` 为真的特征，Write 特征取第一个 `properties.write || properties.writeNoResponse` 为真的特征。

**连接流程**：扫描（名称匹配）→ `createBLEConnection` → `getBLEDeviceServices`（匹配 Service UUID）→ `getBLEDeviceCharacteristics` → `notifyBLECharacteristicValueChange(true)` 订阅 → 链路就绪。未调用 `setBLEMTU`，使用默认 MTU。

---

## 3. 上行命令（小程序 → 设备）

写入 Write 特征，内容为 JSON 文本。

### 3.1 开始呼吸引导 `start_breath_guide`

```json
{
  "cmd": "start_breath_guide",
  "cycles": 6,
  "inhale_ms": 4000,
  "exhale_ms": 5000,
  "duration_ms": 54000
}
```

| 字段 | 类型 | 说明 |
|---|---|---|
| `cmd` | string | 固定 `start_breath_guide` |
| `cycles` | number | 引导循环次数，当前固定 6 |
| `inhale_ms` | number | 单次吸气时长，固定 4000 |
| `exhale_ms` | number | 单次呼气时长，固定 5000 |
| `duration_ms` | number | 总时长，固定 54000 |

下发后设备进入 `BREATH_GUIDE_SESSION` 状态，通过 `device_state` / `resp_debug` 报文持续下发 `guide_text`、`phase_type`、`phase_remaining_ms`。

### 3.2 开始主动检测 `start_active_test`

```json
{
  "cmd": "start_active_test",
  "duration_ms": 60000
}
```

| 字段 | 类型 | 说明 |
|---|---|---|
| `cmd` | string | 固定 `start_active_test` |
| `duration_ms` | number | 检测时长，默认 60000 |

> ⚠️ **待真机验证**：该命令名为小程序侧按 `start_breath_guide` 对称推断，固件是否识别需实测；若不识别需按固件实际命令名调整（仅改 `hold-ble-runtime.js` 一处）。设备也可自行进入 `FINGER_PPG_ACTIVE_TEST` 状态，此时小程序仅作为接收方，全流程不受影响。

---

## 4. 下行报文（设备 → 小程序）

### 4.1 报文类型识别规则

小程序按以下优先级判定报文类型（`detectPacketKind`）：

1. **`msg_type` 字段存在 → 直接作为报文类型**（推荐，固件应显式携带）
2. 同时含 `device_state` + `ble_state` → `device_state`
3. 含 `resp_signal_value` → `resp_debug`
4. 同时含 `i6` + `i7` + `sample_count` + `bpm` → `passive_ppg_batch`
5. 均不匹配 → `unknown`（仅记录调试日志）

非 JSON 文本 → `invalid`（记录原文，不处理）。

### 4.2 `device_state` — 设备状态

| 字段 | 类型 | 说明 |
|---|---|---|
| `device_state` | string | 设备状态机值，见第 5 节 |
| `ble_state` | string | 设备侧 BLE 链路状态描述 |
| `guide_text` | string | 引导/提示文案（`status_text` 为等价别名） |
| `phase_type` | string | 引导阶段类型，仅 `BREATH_GUIDE_SESSION` 下有效 |
| `phase_remaining_ms` | number | 当前阶段剩余毫秒 |

### 4.3 `resp_debug` / `calibration_status` — 呼吸实时流

| 字段 | 类型 | 说明 |
|---|---|---|
| `resp_signal_value` | number | 呼吸波形采样点（追加到呼吸波形序列） |
| `resp_beat_marker_value` | number | 呼吸跳点标记值 |
| `resp_rate_bpm` | number | 当前呼吸率（次/分） |
| `resp_amplitude` | number | 呼吸幅度（调试用） |
| `motion_level` | number | 体动水平（0–1 浮点） |
| `axis_name` | string | 校准轴名，仅 `RESP_CALIBRATING` 下使用 |
| `calibration_step` | number | 校准步骤序号 |
| `guide_text` | string | 引导文案（可选，覆盖前值） |
| `phase_type` | string | 阶段类型（校准时复用） |
| `phase_remaining_ms` | number | 阶段剩余毫秒 |

### 4.4 `active_realtime` — 指部 PPG 实时单点

| 字段 | 类型 | 说明 |
|---|---|---|
| `i6_filtered_point` | number | I6 滤波后 PPG 单点 |
| `i7_beat_marker` | number | I7 beat 标记单点 |
| `heart_rate_bpm` | number | 实时心率 |
| `quality_score` | number | 信号质量分（0–100） |
| `beat_count` | number | 累计检出 beat 数 |
| `contact_present` | bool | 手指接触状态 |
| `measurement_id` | number | 所属测量 ID |

### 4.5 `active_realtime_batch` — 指部 PPG 实时批量

| 字段 | 类型 | 说明 |
|---|---|---|
| `i6` | number[] | I6 滤波波形批量点（= 固件 `filtered_ir`，beat 检测链输入） |
| `i7` | number[] | I7 beat 标记批量点 |
| `measurement_id` | number | 测量 ID |
| `sample_count` | number | 本批点数 |
| `dt_ms` | number | 采样间隔（毫秒） |
| `ts_ms_end` | number | 本批末点设备时间戳 |
| `bpm` | number | 实时心率 |
| `bc` | number | 累计 beat 数 |
| `i12` | number | 最近一次 beat 间期（毫秒） |
| `qs` | number | 信号质量分 |
| `cp` | number/bool | 接触状态（非 0 即贴合） |

小程序按 `measurement_id` 累积完整实时波形（上限 6000 点 ≈ 60s × 100Hz），用于在窗口元数据到达前先完成归档。

#### 4.5.1 情感检测所需的去趋势 IR（**固件待补字段**）

PPG 情感检测接口 `/api/ppg_predict` 的 `sig` 训练口径是 `detrended_ir`
（`raw_ir - dc_estimate_`，见 `captures/max30102_finger/*/README.md`），**不能用 `i6` 顶替**：

> 用 2026-06-23 手指采集数据实测：把 `filtered_ir`（= `i6`）和 `detrended_ir`
> 分别过服务端预处理（重采样 50Hz → 0.5–10Hz 带通 → 30s 切窗 → 百分位 z-norm），
> 两者相关度只有 **0.68**，平均相对偏差 **76%**；而 `raw_ir` 与 `detrended_ir`
> 的相关度是 **0.987**。`i6` 在固件里已经多了一层平滑，再被服务端带通一次会双重滤波。

因此本批报文需要补充下列字段（任选其一，按优先级消费）：

| 字段 | 类型 | 优先级 | 说明 |
|---|---|---|---|
| `i5` | number[] | 1（最优） | 去趋势 IR，即 `detrended_ir`；别名 `detrended` / `detrended_ir` 亦可 |
| `raw_ir` | number[] | 2 | MAX30102 原始 IR 通道值；别名 `rawir` / `raw` |
| `avg_ir` | number[] | 3（配合 `raw_ir`） | IR 直流估计均值；别名 `avgir` / `avg`。**与 `raw_ir` 同时下发时**小程序按 `raw_ir - avg_ir` 复现固件去趋势（实测与固件 `detrended_ir` 相关度 0.9857）；只下发 `raw_ir` 时小程序本地做 EMA 去直流（相关度 0.9982） |

三个数组的长度需与 `i6` 一致，共用 `ts_ms_end` / `dt_ms` 还原同一套时间戳。
未下发任何一路时，首页「状态识别」会直接提示缺字段，不会静默拿 `i6` 兜底。

### 4.6 `passive_resp_window` — 被动呼吸窗口

设备周期性完成一个被动监测窗口后上报，触发日级聚合。

| 字段 | 类型 | 说明 |
|---|---|---|
| `window_id` | number | 窗口 ID |
| `window_end_ts_ms` | number | 窗口结束时间戳（用于按天归档） |
| `resp_rate_bpm` | number | 窗口平均呼吸率 |
| `quality_score` | number | 窗口质量分 |
| `motion_level` | number | 窗口体动水平 |
| `point_count` | number | 窗口点数 |

### 4.7 `passive_ppg_batch` — 胸口 PPG 批量

| 字段 | 类型 | 说明 |
|---|---|---|
| `i6` | number[] | 胸口 PPG 波形批量点 |
| `i7` | number[] | 胸口 PPG beat 标记批量点 |
| `sample_count` | number | 本批点数 |
| `bpm` | number | 当前心率 |
| `qs` | number | 信号质量分 |

识别依赖第 4.1 节的字段启发式（`i6+i7+sample_count+bpm`），**建议固件显式携带 `msg_type`**。

### 4.8 `active_window` — 主动检测窗口（分片协议）

检测完成后设备分片下发窗口元数据，按 `measurement_id` 重组。

**元数据字段**：

| 字段 | 类型 | 说明 |
|---|---|---|
| `measurement_id` | number | 测量 ID（与实时批量关联） |
| `session_id` | number | 会话 ID（可选） |
| `fragment_index` | number | 当前分片序号 |
| `fragment_total` | number | 分片总数 |
| `sample_start_ts_ms` / `sample_end_ts_ms` | number | 采样起止时间戳 |
| `heart_rate_bpm` | number | 窗口平均心率 |
| `quality_score` | number | 窗口质量分 |
| `processed_point_count` | number | 处理后总点数 |
| `beat_count` | number | beat 总数 |
| `rr_interval_count` | number | RR 间期总数 |

**分片数据字段**（按 offset 写入对应数组）：

| 字段 | 类型 | 说明 |
|---|---|---|
| `processed_point_offset` | number | 波形分片起始下标 |
| `processed_points_fragment` | number[] | 处理后波形分片 |
| `beat_offset` | number | beat 时间戳分片起始下标 |
| `beat_ts_ms_fragment` | number[] | beat 时间戳分片 |
| `rr_intervals_ms_fragment` | number[] | RR 间期分片（从头填充，无 offset） |

**完成判定**：已收分片数 = `fragment_total` 且 `processedPoints`、`rrIntervalsMs` 无空洞。

**实时兜底**：若分片未到齐但实时累积波形已达预期点数 90%（或 ≥ 1200 点、或时长 ≥ 55 秒），小程序以实时累计结果先行归档，分片到齐后二次覆盖归档（同 id upsert）。

### 4.9 `debug_log` / `error_status` — 日志报文

| 报文 | 字段 | 说明 |
|---|---|---|
| `debug_log` | `message` | 设备调试文本，直接进调试日志 |
| `error_status` | `error_code`、`error_message` | 设备错误上报 |

---

## 5. 设备状态机（`device_state` 已知取值）

| 状态值 | 含义 | 小程序行为 |
|---|---|---|
| `RESP_CALIBRATING` | 呼吸校准中 | 显示轴名、校准步骤、引导文案 |
| `BREATH_GUIDE_SESSION` | 呼吸引导进行中 | 显示阶段类型与剩余时间，主按钮变为"引导进行中" |
| `FINGER_PPG_ACTIVE_TEST` | 指部 PPG 主动检测中 | 首页显示 60 秒进度、实时心率与 beat 数 |
| 其他值 | 常规监测 | 仅更新状态文案与调试日志 |

---

## 6. 主动检测完整时序

```
小程序                     设备
  |---- start_active_test --->|  （可选，设备也可自行开始）
  |                           |  进入 FINGER_PPG_ACTIVE_TEST
  |<-- active_realtime_batch--|  实时 I6/I7 波形 + 心率/beat（持续 60s）
  |<-- active_realtime_batch--|  ...
  |<-- active_window (1/N) ---|  窗口元数据分片
  |<-- active_window (N/N) ---|  分片到齐 → 完整归档
  |                           |  离开 FINGER_PPG_ACTIVE_TEST
```

- 实时流与窗口元数据**可能乱序**：小程序用 `pendingActiveRealtimeMeasurements` 与 `pendingActiveWindows` 两个暂存表按 `measurement_id` 关联
- 归档以**实时累计波形为准**（完整 60 秒），分片数据用于补充处理后波形与 RR 间期
- 归档完成后自动触发一次云端整体分析刷新

---

## 7. 待确认事项

| 项 | 状态 |
|---|---|
| `start_active_test` 命令名 | ⚠️ 小程序侧推断，需固件确认 |
| `device_state` 完整取值集合 | 代码仅消费上述 3 个值，其余按未知状态处理 |
| `passive_ppg_batch` 无 `msg_type` 时依赖字段启发式 | 建议固件显式携带 `msg_type` |
| `active_realtime_batch` 缺 `i5` / `raw_ir` | ⚠️ 情感检测需要 `detrended_ir`，见 4.5.1；未补充前首页「状态识别」会提示缺字段 |
| MTU / 长 JSON 分包 | 小程序未协商 MTU；若单条 JSON 超过默认 MTU，需固件侧分包或双方协商 |
| `calibration_status` 与 `resp_debug` 字段差异 | 小程序同函数处理，字段全集以固件为准 |

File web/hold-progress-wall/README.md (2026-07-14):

# HOLD 进度墙

用于 2 到 3 人协作查看彼此开发进展的小型记录网站。

## 当前实现

- 顶部轻量甘特时间轴
- 记录详情与图片侧栏
- 邮箱 Magic Link 登录
- 管理员白名单后台
- 成员昵称与颜色自定义
- 基于 Supabase Realtime 的近实时刷新

## 本地开发

```bash
npm install
npm run dev
```

如果你和当前仓库一样希望把依赖尽量放到 D 盘，可以先把 `node_modules` 建成指向 D 盘的 Junction，再执行安装。

## 环境变量

项目已提供：

- [.env.local.example](.env.local.example)：模板
- [.env.local](.env.local)：当前本地开发值

线上部署到 Vercel 时，请在项目设置里配置：

- `NEXT_PUBLIC_SUPABASE_URL`
- `NEXT_PUBLIC_SUPABASE_PUBLISHABLE_KEY`
- `NEXT_PUBLIC_ADMIN_EMAIL`

## Supabase 初始化

1. 打开 Supabase 项目的 SQL Editor。
2. 执行 [supabase/schema.sql](supabase/schema.sql)。
3. 在 Authentication 中确认 Email 登录已开启。
4. 在 URL Configuration 中加入本地地址和后续的 Vercel 地址。
5. 首次使用管理员邮箱登录后，再去后台添加其他成员白名单。

## 目录说明

- `src/app`：页面入口与全局样式
- `src/components`：登录、时间轴、详情、编辑器、后台等页面组件
- `src/lib`：类型、配置、Supabase 客户端与示例数据
- `supabase/schema.sql`：数据库与存储初始化脚本

## 部署建议

1. 将本目录推到 GitHub。
2. 在 Vercel 导入该项目。
3. 配置环境变量。
4. 触发首次部署。
5. 使用管理员邮箱登录并进入后台添加成员。
This is a [Next.js](https://nextjs.org) project bootstrapped with [`create-next-app`](https://nextjs.org/docs/app/api-reference/cli/create-next-app).

## Getting Started

First, run the development server:

```bash
npm run dev
# or
yarn dev
# or
pnpm dev
# or
bun dev
```

Open [http://localhost:3000](http://localhost:3000) with your browser to see the result.

You can start editing the page by modifying `app/page.tsx`. The page auto-updates as you edit the file.

This project uses [`next/font`](https://nextjs.org/docs/app/building-your-application/optimizing/fonts) to automatically optimize and load [Geist](https://vercel.com/font), a new font family for Vercel.

## Learn More

To learn more about Next.js, take a look at the following resources:

- [Next.js Documentation](https://nextjs.org/docs) - learn about Next.js features and API.
- [Learn Next.js](https://nextjs.org/learn) - an interactive Next.js tutorial.

You can check out [the Next.js GitHub repository](https://github.com/vercel/next.js) - your feedback and contributions are welcome!

## Deploy on Vercel

The easiest way to deploy your Next.js app is to use the [Vercel Platform](https://vercel.com/new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) from the creators of Next.js.

Check out our [Next.js deployment documentation](https://nextjs.org/docs/app/building-your-application/deploying) for more details.

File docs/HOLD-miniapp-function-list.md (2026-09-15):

# HOLD miniapp function list for swimlane design

## L0 核心闭环

- 用户目标
  - 戴上设备
  - 连接设备
  - 完成基础校准
  - 开始呼吸引导
  - 看到实时状态
  - 停止引导或断开设备

- 小程序首页
  - 扫描并连接
  - 显示连接状态
  - 显示校准状态
  - 开始基础校准
  - 开启/停止呼吸引导
  - 显示实时指标
  - 显示关键提示

- 硬件
  - BLE 广播
  - BLE 连接
  - Notify 状态上报
  - Write 命令接收
  - DRV2605 呼吸震动
  - DRV2605 校准脉冲
  - 传感器状态采样

## L1 首页信息架构

- 连接区
  - 设备名
  - 蓝牙适配器状态
  - BLE 连接状态
  - 主操作：扫描并连接
  - 辅操作：断开连接

- 校准与引导区
  - 当前引导标题
  - 当前引导说明
  - 当前链路提示
  - 基础校准按钮
  - 呼吸引导按钮

- 实时指标区
  - 呼吸 bpm
  - 心率 bpm
  - beat 数
  - 运动状态
  - 呼吸/校准阶段
  - 传感器型号或轴向

- 诊断入口
  - 查看调试曲线
  - 删除本地调试缓存

## L2 调试页功能

- 链路诊断
  - BLE adapter 状态
  - 设备连接状态
  - 设备名
  - 设备状态
  - 最近包类型
  - 当前引导状态

- BLE 操作
  - 扫描并连接
  - 断开连接
  - 清空调试窗口
  - 开始/停止呼吸反馈
  - 基础校准

- 数据窗口
  - 呼吸 bpm
  - 心率 bpm
  - motion
  - beat count
  - 状态 / 传感器
  - haptic ready
  - raw text
  - raw hex

- 云函数验证
  - button press 事件提交
  - 云端存储路径
  - LLM 返回摘要
  - 错误提示

## L3 异常与恢复

- 蓝牙未开启
  - 首页提示打开手机蓝牙和小程序权限
  - 保留扫描按钮

- 未发现设备
  - 显示正在寻找 `HOLD-INTEGRATED`
  - 允许重新扫描

- 找不到服务
  - 提示烧录 integrated BLE 固件
  - 引导进入调试页

- 找不到 notify 特征
  - 提示固件协议不匹配
  - 保留 raw/hex 调试入口

- 找不到 command 特征
  - 禁用校准和呼吸按钮
  - 提示当前固件没有命令写入特征

- 收到无法解析数据
  - 显示 binary 包长度和 hex
  - 不阻塞连接状态

## L4 后续增强

- 呼吸算法
  - 将 IMU 呼吸估计合并进 integrated firmware
  - 上报真实 respiration bpm
  - 上报 inhale/exhale 置信度

- 佩戴质量
  - PPG contact 状态
  - 压力贴合等级
  - 佩戴不稳提醒

- 引导体验
  - 呼吸节奏可选
  - 震动强度可调
  - 校准倒计时
  - 完成后的轻提示

- 数据闭环
  - 本地 session 记录
  - 云端事件同步
  - 调试日志导出

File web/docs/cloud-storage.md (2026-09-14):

# HOLD 小程序云端存储说明

小程序已不再把健康数据写进本地 `wx.setStorageSync`，全部改由**微信云开发**承载：
数据落在云开发数据库，读写统一走云函数 `health_store`，按 `openid` 做用户隔离。
换手机、清缓存、重装小程序后，只要用同一个微信账号登录，历史记录都可以恢复。

## 数据分布

| 集合 | 作用 | 关键字段 |
| --- | --- | --- |
| `hold_user_state` | 每个用户一行：最近实时波形缓存、最近被动/主动窗口、整体分析结论 | `openid`、`latestPassiveWindow`、`latestActiveWindow`、`overallSummary`、`respWavePoints`、`chestPpgWavePoints` |
| `hold_active_measurements` | 指部主动检测归档（默认保留 30 条） | `openid`、`recordId`、`record`、`wave` |
| `hold_daily_analyses` | 被动监测日级归档（默认保留 21 天） | `openid`、`dayKey`、`record`、`wave` |
| `hold_users` | 账号档案（详见 [用户系统](./user-system.md)） | `_openid`、`nickname`、`avatarUrl`、`last_login_at_ms` |

读取范围由账号状态决定：已登录读 `scope=mine`（仅本账号），
未登录回落 `scope=shared`（本机全部成员记录）。详见下方「数据范围」。

### record / wave 分离

大段波形数组（`wave`）与轻量记录（`record`）分开存：

- 测量记录：`fullPpgWavePoints`、`fullPpgBeatMarkerPoints`
- 日级记录：`respWavePoints`、`respBeatMarkerPoints`、`chestPpgWavePoints`、`chestPpgBeatMarkerPoints`

拉取列表时**不带波形**，只有打开具体报告/具体某一天时才调用 `load_detail` 补拉，
避免单次网络传输几十 KB～数 MB 的数组。

## 部署状态（已部署）

| 项 | 值 |
| --- | --- |
| 环境 ID | `hold-dev-env-d2gukfp01ac296189`（别名 `hold-dev-env`，ap-shanghai，体验版） |
| 云函数 | `health_store`、`health_account` 均已部署（Nodejs16.13，`index.main`） |
| 集合 | 四个集合均已创建（下表） |
| 索引 | `openid+recordId`、`openid+dayKey`、`updated_at_ms` 均已建立 |

已建索引：

| 集合 | 索引 |
| --- | --- |
| `hold_active_measurements` | `idx_openid_record`（openid + recordId）、`idx_updated`（updated_at_ms 倒序） |
| `hold_daily_analyses` | `idx_openid_day`（openid + dayKey）、`idx_updated`（updated_at_ms 倒序） |
| `hold_user_state` | `idx_openid`（openid） |
| `hold_users` | `_openid_1`（云开发自动创建） |

### 需要重新部署时

代码改动后重新部署（任选其一）：

1. 微信开发者工具：右键 `cloudfunctions/health_store` → **上传并部署：云端安装依赖**；
2. CloudBase CLI：`tcb fn deploy health_store --dir cloudfunctions/health_store`；
3. 让 AI 助手通过 CloudBase MCP 重新部署。

> 数据库权限保持默认的「仅创建者可读写」即可 —— 本项目所有数据访问都经过
> 云函数（云函数以管理端身份运行，不受集合权限规则限制），小程序端不直接读写数据库。
> 这样即使有人拿到小程序端代码也无法越权读取他人健康数据。

## 数据范围

| scope | 触发条件 | 读取范围 |
| --- | --- | --- |
| `mine` | 已登录 | 只读当前微信账号的记录 |
| `shared` | 未登录 | 读本机全部成员的记录 |

登录状态变化时，会先 flush 待写队列（避免写到新身份下），再按新 scope 重新拉取。

## 客户端改动一览

- `utils/hold-cloud-store.js`：云函数调用封装，内含防抖合并、失败重试一次、进入后台前 flush。
- `utils/hold-ble-runtime.js`：
  - 删除 `hold_ble_runtime_state_v2` 本地存储读写；
  - 启动时异步 `pull` 一次全量轻量数据，写操作改为增量 upsert；
  - 新增 `ensureMeasurementWaves` / `ensureDailyAnalysisWaves` 按需补波形；
  - 新增 `getCloudStatus` / `flushCloudWrites` / `waitForHydration`。
- `app.js`：`onHide` 时 flush 未完成写入。
- `pages/debug/index.js`：状态栏由「本地存储」改为「云端存储」，显示同步状态、数据范围与归档条数；
  「删除全部数据缓存」改为删除云端数据。
- `utils/hold-account.js`：微信登录与账号档案，详见 [用户系统](./user-system.md)。

## 状态说明

`state.cloudStatus` 取值：

| 值 | 含义 |
| --- | --- |
| `idle` | 尚未开始同步 |
| `loading` | 正在从云端恢复 |
| `ready` | 云端已连接 |
| `error` | 拉取或写入失败，`state.cloudError` 为原因 |
| `unavailable` | 当前基础库环境不支持云开发 |

## 已知取舍

- 实时滚动缓存里的胸口 PPG 波形落云时会抽稀到 1500 点（跳点序列保留峰值），
  完整波形仍保存在每次主动检测归档与日级归档里。
- 云端写入有约 0.8～1.5 秒防抖；极端情况下（立刻杀进程）可能丢最后一次写入，
  下一次数据变化会重新覆盖写入。

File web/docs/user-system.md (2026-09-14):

# HOLD 小程序用户系统说明

用户系统基于**微信云开发**实现：小程序端不接触 `openid`，
登录时由云函数用 `cloud.getWXContext()` 直接取，避免身份标识被伪造。
首次打开小程序即自动建号，无需额外注册步骤。

## 数据模型

| 集合 | 作用 | 关键字段 |
| --- | --- | --- |
| `hold_users` | 账号档案，一人一条 | `_openid`（微信身份，系统写入不可伪造）、`nickname`、`avatarUrl`、`created_at_ms`、`last_login_at_ms`、`loginCount` |

健康数据集合（`hold_user_state` / `hold_active_measurements` / `hold_daily_analyses`）
新增两个归属字段语义：

- `_openid`：写入时由数据库自动带上，**不可伪造**，是真正的归属标识；
- `openid`：业务字段。已登录时存**账号身份**，未登录时回落为该设备成员的真实 openid。

## 登录流程

```
小程序启动
  └─ holdAccount.login()                    ← app.js onLaunch，静默执行
       └─ wx.cloud.callFunction(health_account / login)
            └─ 云函数取 WXContext.OPENID
                 ├─ hold_users 无档 → 建号（昵称默认「微信用户」）
                 └─ 有档 → 更新 last_login_at_ms、loginCount +1
```

失败不阻断启动：未登录时读取会回落到**设备共享范围**，
新用户在没有登录的情况下也能看到这台设备此前归档的数据。

## 两种数据范围

| scope | 触发条件 | 读取范围 |
| --- | --- | --- |
| `mine` | 已登录 | 只读当前微信身份的记录 |
| `shared` | 未登录 | 读本机全部成员的记录（`_openid` 前缀匹配） |

登录状态变化时，`hold-ble-runtime` 会先把待写队列 flush（避免写到新身份下），
再按新的 scope 重新 `pull` 一次。

> 设计取舍：微信小程序内的 `openid` 是**同一 appid 身份空间**，
> 所以 `shared` 语义是「这台设备上的所有使用者」，而不是任意跨用户公开读。
> 如果后续要支持多个家庭成员的独立档案与互相授权，需要再加一层显式的
> 成员绑定与授权集合。

## 昵称与头像

`wx.getUserProfile` 与 `<open-data>` 已经无法拿到真实昵称头像，所以：

- **昵称**：默认「微信用户」，用户在「我的」页可手动修改（≤20 字），
  输入框用 `type="nickname"`，会带出微信键盘的昵称快捷输入；
- **头像**：`<button open-type="chooseAvatar">` 让用户自选，
  拿到的是本地临时路径，由云函数 `health_account` 转存到云存储
  `avatars/{openid}/{时间戳}.png` 并回存 `cloud://` 文件 ID。

## 页面

新增 tab「我的」（`pages/profile/index`）：

- 未登录：微信官方登录卡片形态，一键登录按钮；
- 已登录：头像（可点击更换）、昵称（可改名）、云端数据统计、
  同步状态与数据范围、账号 ID 尾号、注册时间、登录次数、退出登录。

「退出登录」只清除本地账号态，**不删除云端记录**，重新登录即可恢复。

## 部署状态（已部署）

`health_account` 与 `health_store` 均已部署到环境
`hold-dev-env-d2gukfp01ac296189`（Nodejs16.13，入口 `index.main`），
`hold_users` 集合已创建，`_openid` 索引由云开发自动维护。
健康数据集合与索引见 [云端存储说明](./cloud-storage.md)。

代码改动后重新部署：开发者工具右键函数目录「上传并部署：云端安装依赖」，
或 `tcb fn deploy health_account --dir cloudfunctions/health_account`。

数据库权限保持默认「仅创建者可读写」即可：所有访问都经云函数（管理端身份，
不受集合权限规则约束），小程序端不直接读写数据库。

## 可用性设计

`hold-account.js` 调用登录时优先走 `health_account`，
若该云函数尚未部署（返回错误或调用失败），会自动退回
`health_store / user_sync`。两条路径写入同一个 `hold_users` 集合，
所以少部署一个云函数也能跑通。

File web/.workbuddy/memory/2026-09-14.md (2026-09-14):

# 2026-09-14

## HOLD 小程序：本地存储迁移到微信云开发

- 新建云函数 `cloudfunctions/health_store`，统一按 `openid` 读写三个集合：
  - `hold_user_state`（实时波形缓存 + 最近窗口 + 整体分析结论，每人一行）
  - `hold_active_measurements`（指部主动检测，recordId 唯一，保留 30 条）
  - `hold_daily_analyses`（被动日级归档，dayKey 唯一，保留 21 天）
- 新增 `utils/hold-cloud-store.js`：云函数封装，含防抖合并（state 1.5s / 记录 0.8s）、失败重试一次、`flush()`、`bootstrap()`。
- `utils/hold-ble-runtime.js`：删除 `hold_ble_runtime_state_v2` 本地 Storage 读写；改为启动时异步 `pull`、写操作增量 upsert。
- 关键设计：**record / wave 分离**。大波形数组单独存 `wave` 字段，列表拉取用纯包含投影排除，打开具体报告时再 `load_detail` 补拉，避免单次返回过大（日级 21 天 × 12000 点会爆 1MB）。
- 回写保护：`updateActiveMeasurementReport` 等只改摘要的场景传 `keepWave: true`，内存里波形未加载时不覆盖云端波形。
- 实时胸口 PPG 缓存落云时抽稀到 1500 点，跳点序列用 preservePeaks 防止把 0 段糊成有跳点。
- 页面改动：`active-report` onLoad 触发 `ensureMeasurementWaves`；`daily-analysis` 新增 `requestDailyWaves` 按需补拉；`debug` 页状态栏改为云端存储状态。
- 部署说明写在 `docs/cloud-storage.md`。

## HOLD 小程序：用户系统与微信登录

- 新建云函数 `cloudfunctions/health_account`（`login` / `update_profile` / `get_profile`），
  新增集合 `hold_users`（一人一条，`_openid` 为归属键）。
- 新增 `utils/hold-account.js`：登录态管理（anonymous / signing / ready / error）、
  subscribe 订阅、`updateProfile`、`fetchStats`、`logout`。
  **openid 不下发到小程序端**，由云函数 `getWXContext()` 直取，避免伪造。
- 启动静默登录（`app.js onLaunch`），失败不阻断；首登自动建号。
- **两种数据范围**：已登录 `scope=mine`（仅本账号），未登录回落 `scope=shared`（本机全部成员），
  这样新用户没登录也能看到设备已归档的历史。登录态变化时先 flush 待写队列再按新 scope 重拉。
- 昵称/头像：`wx.getUserProfile` 和 `open-data` 已失效，改为可编辑昵称（`type="nickname"` 输入框）
  + `<button open-type="chooseAvatar">`，头像临时路径由云函数转存到云存储 `avatars/{openid}/`。
- 新增「我的」tab（`pages/profile`），4 个 tab 的图标按现有规范代码生成
  （81×81 RGBA、线性描边、灰 `#9A9A8E` / 绿 `#2F5D3A`、超采样抗锯齿，见临时脚本思路）。
- `health_store` 扩展 `user_sync` / `user_profile` / `user_stats`，作为未部署 `health_account` 时的兜底。
- 文档：`docs/user-system.md`；`docs/cloud-storage.md` 同步更新范围说明。
- 验证方式：用 node 桩 wx 环境跑通账号层与 scope 切换（anonymous→shared / ready→mine / logout→shared）。

## 修复：「我的」tab 图标不显示

- 现象：tabBar 第 4 项「我的」无图标。`app.json` 配置本身正确，问题在 PNG 文件内容。
- 前两次生成失败：几何用「大圆弧 + 挖空」思路，超采样距离场算错，
  产出实心色块（bbox 79×56 顶到画布边缘、2319 像素），且形状完全不像人像。
- **正确做法（可复用）**：改用 **无符号距离场（SDF）+ 4× 超采样**。
  - 头部 = 圆环：`abs(hypot(p-c) - r)`
  - 肩部 = 圆弧：`theta = atan2(dx, -dy)`，`|theta| <= thetaMax` 时取 `abs(dist - R)`，
    否则回落到弧两端点的距离（这样圆弧有干净的圆头端点）
  - 描边宽度 5.5px 与现有图标（5~6px）一致：`alpha = clamp(half - d + 0.5, 0, 1)`
  - 几何：`HEAD={x:40.5,y:28,r:10.5}`、`BODY={x:40.5,y:79.5,r:32.5,θmax:60°}`
  - 结果 bbox 63×52，中心 (40, 39.5)，888 像素 —— 与 home(61×56)、history(59×59) 同规格
- 顺带把 `pages/profile` 登录卡片插画从复用 `tab-user-active.png`（81px 放大会糊）
  改为独立生成的 `images/login-avatar.png`（168×168，同款 SDF 几何等比缩放）。
- 图标生成脚本思路记在 `~/.workbuddy/skills/wechat-miniprogram-cloud-user-system` 相关笔记里，
  以后需要新增 tab 图标可直接复用这套 SDF + PNG 手写编码方案。
- 验证：Pillow 交叉校验全部 9 个 RGBA 资源；node 桩环境冒烟跑通 profile 页
  （onLoad / applyAccountState / applyRuntimeState / onUnload）+ tabBar 配置校验 + 45 个样式类覆盖。

### 真正根因（第一轮误判，第二轮才找到）

上面第一轮把原因归到「PNG 图形畸形」是**误判**。修好图形后图标依然不显示，
重新排查才找到真凶：

**`project.private.config.json` 的 `"ignoreDevUnusedFiles": true`**

这是开发者工具「详情 → 本地设置 → 忽略无依赖文件」开关。开启时 DevTools 按
**依赖图缓存**剔除它认为没被引用的文件。新增图片若只被 `app.json` 的 tabBar
引用，依赖图缓存未刷新就会被过滤出编译产物 → **tabBar 文字照常显示、图标区空白**。

判定依据（这套排除法很管用）：
1. `app.json` tabBar 配置逐项校验通过（pagePath 已注册、iconPath 文件存在）；
2. 生成的 PNG 与能正常显示的图标**逐字节同构**（同为 8bit RGBA、非隔行、
   IHDR/IDAT/IEND、CRC 全 OK），Pillow 也能正常解码 → 排除编码问题；
3. 全项目搜索 `setTabBarItem` / `custom-tab-bar` / `"custom":` 均无命中 → 排除运行时覆盖；
4. `packOptions.ignore` 只忽略两个无关文件夹 → 排除打包过滤；
5. **决定性证据**：三个内容完全不同、像素数分别 1344 / 2319 / 888 的图片
   全都显示不出来 → 内容不是原因，是文件根本没进编译产物。

修复：`project.private.config.json` 改 `"ignoreDevUnusedFiles": false`，
再「清缓存 → 重新编译」。真机预览对应的是 `ignoreUploadUnusedFiles`（UI 里同一个开关），
若用真机验证需一并确认。

**以后新增 tabBar 图标 / 任何只被 app.json 引用的静态资源，先确认这个开关。**

## 云开发环境清单（CloudBase 实测）

- **环境 ID**：`hold-dev-env-d2gukfp01ac296189`，别名 `hold-dev-env`，状态 NORMAL，默认环境
- 地域 `ap-shanghai`，类型 baas，**套餐 体验版（baas_trial）**，2026-12-17 到期
- 后端 `RuntimeMode: nosql`（**未开通 PG/MySQL**）→ 数据一律走 `app.database()` 文档库，
  权限用 `managePermissions(resourceType="noSqlDatabase")`，不要写 PG 的 RLS
- 存储桶 `686f-hold-dev-env-d2gukfp01ac296189-1444609081`
- 静态域名 `hold-dev-env-d2gukfp01ac296189-1444609081.tcloudbaseapp.com`
- 绑定小程序 AppID `wxfa0d59d81b76a71a`，环境来源 `ide`
- 代码里 3 处硬编码该 env：`app.js` 的 `wx.cloud.init`、
  `cloud_hosting/miniprogram_hosting.js` 的 `ENV_ID`、`cloud_hosting/README.md` 示例；
  4 个云函数统一用 `cloud.DYNAMIC_CURRENT_ENV`（跟随部署环境，正确做法）

### 部署记录（2026-09-14 完成）

通过 CloudBase MCP 部署，环境 `hold-dev-env-d2gukfp01ac296189`：

- 云函数 `health_store` / `health_account`：已创建并部署，Nodejs16.13，入口 `index.main`，
  timeout 20s，Status Active。冒烟调用均返回 `{"code":401,"error_message":"missing openid"}`
  （预期值，证明代码执行正常、wx-server-sdk 加载成功）
- 集合 4 个：`hold_user_state` / `hold_active_measurements` / `hold_daily_analyses` / `hold_users`
- 索引：`hold_active_measurements` 上 `idx_openid_record`(openid+recordId) + `idx_updated`(updated_at_ms 倒序)；
  `hold_daily_analyses` 上 `idx_openid_day`(openid+dayKey) + `idx_updated`；
  `hold_user_state` 上 `idx_openid`。`hold_users._openid_1` 云开发自动建，无需手动加
  （手动建会报 IndexOptionsConflict）

**踩坑**：`manageFunctions` 的 `func` 对象不接受 `installDependency` 字段（schema 严格，
报 "must NOT have additional properties"），依赖安装要用 `isWaitInstall: true`。

**权限结论**：数据库权限保持默认「仅创建者可读写」即可，不用改成「仅管理端可读写」。
因为本项目所有数据访问都经云函数，而**云函数以管理端身份运行、不受集合安全规则限制**；
安全规则只约束小程序端直连数据库。这样既安全又不用额外配置。

部署步骤已写进 `docs/cloud-storage.md` 和 `docs/user-system.md`（原「部署步骤」章节
改为「部署状态（已部署）」）。

## 梳理蓝牙连接逻辑（只读分析，未改代码）

- 蓝牙逻辑集中在两个文件：
  - `utils/hold-ble-runtime.js`（2000+ 行单例 runtime：连接 + 状态机 + 波形缓存 + 归档 + 云同步）
  - `utils/ble-debug-protocol.js`（UUID 常量、notify 解析、设备/特征匹配）
- 入口：`app.js onLaunch` → `holdBleRuntime.init()`（注册 onBLECharacteristicValueChange /
  onBluetoothDeviceFound / onBLEConnectionStateChange + 云端 hydrate）；
  扫描触发点 `pages/home/index.js:287` 与 `pages/debug/index.js:289`。
- 连接链路：openBluetoothAdapter → startBluetoothDevicesDiscovery → onBluetoothDeviceFound
  （名称含 HOLD-INTEGRATED）→ stopDiscovery → createBLEConnection(10s) → getBLEDeviceServices
  → getBLEDeviceCharacteristics → notifyBLECharacteristicValueChange(true) → 就绪。
- 重连：`scheduleAutoReconnect` 1.2s 延时，`reconnectAttemptsRemaining` 初始 3，
  `manualDisconnectRequested` 为真时不重连；连接成功把次数清零。
- GATT：Service 19b10010 / Notify 19b10011 / Write 19b10012（后缀 e8f2-537e-4f6c-d104768a1214），
  精确匹配失败时按 properties 兜底。
- 协议文档见 `docs/ble-interface.md`。
- 待办/风险（未改）：`start_active_test` 命令名未经固件真机确认；未协商 MTU；
  `app.json` / `project.config.json` 未见蓝牙或定位权限声明字段（真机扫描可能需要）。

## 接入 PPG 情感检测云托管接口（首页「状态识别」卡片）

- 依据 `cloud_hosting/README.md`：`POST /api/ppg_predict`，入参 `{t_ms, sig}`，
  返回三分类 `基线(0)/压力(1)/愉悦(2)`；默认 30s 窗口、15s 步长，60s 数据切 3 段。
- 新增 `utils/ppg-predict.js`：`buildPredictSeries`（拼时间轴 + 30.5s 时长校验）、
  `callPpgPredict`（`wx.cloud.callContainer`，env `hold-dev-env-d2gukfp01ac296189`、
  service `ppg-predict`）、`summarizePredictResult`、`checkHealth`。
  多段结果按**概率平均**取总标签，另保留每段明细。
- **关键改动**：接口要 `t_ms`（device_uptime_ms），但 runtime 原先只存波形值。
  在 `hold-ble-runtime.js` 的 pending 测量里新增 `tsPoints`，由
  `active_realtime_batch` 的 `ts_ms_end - (n-1)*dt_ms` 逐点还原，与 `wavePoints`
  同长度同裁剪（6000 点上限）；落记录为 `fullPpgTsMs`（并入 `MEASUREMENT_WAVE_KEYS`
  走 wave 分离存储），另存 `sampleIntervalMs` 供无时间戳时回退重建时间轴。
- 首页触发：检测开始 `armed = now + 3min`，归档完成且 `!isPartial` 时对
  **新 measurement id** 只调一次；用 `wasActiveTestRunning` + id 去重，
  避免进页面时被云端历史记录误触发。错误态给「重新识别」。
- 信号来源：指部 I6 滤波波形（`fullPpgWavePoints`），**不是文档说的 `detrended_ir`**，
  服务端会再走一次 0.5–10Hz 带通，属近似替代，真机需核对准确率。

### 纠正：必须改用 detrended_ir（i6 不能用）

- **口径**：`detrended_ir = raw_ir - dc_estimate_`（固件 EMA 去直流）；
  `filtered_ir` = detrended 之后再平滑，是 beat 检测链输入。见
  `captures/max30102_finger/20260623_153735/README.md` 第 6、7 列说明。
- **BLE 字段映射**：`i6` = `filtered_ir`，`i7` = `beat_marker`。
  `detrended_ir` 固件里算了（`heart_rate_estimator.h` 的私有成员 `dc_estimate_`）
  但**没有通过 BLE 上报**，`raw_ir` 也没上报。
- **实测（2026-06-23 手指 CSV，1505 点 / 60s / 25Hz，过服务端完整预处理后对比）**：
  - `filtered_ir`(i6) vs `detrended_ir`：相关度 **0.68**，平均相对偏差 **76%** → 不能互换
  - `raw_ir` vs `detrended_ir`：相关度 **0.987**
  - `raw_ir - avg_ir` vs `detrended_ir`：相关度 **0.9857**
  - 本地 EMA 去直流(tau=1s) vs `detrended_ir`：相关度 **0.9982**（最优回退）
- **实现**：`ppg-predict.js` 新增 `resolveSignalSource` / `detrendSignal`，
  优先级 `fullPpgDetrendedIr` > `raw-avg` > `raw 本地去直流`；
  `ALLOW_FILTERED_FALLBACK` 默认 **false**，缺字段直接报错而不是静默用 i6。
- 运行时新增 `detrendedPoints` / `rawIrPoints` / `avgIrPoints` 三路与波形对齐采集，
  落记录为 `fullPpgDetrendedIr` / `fullPpgRawIr` / `fullPpgAvgIr`（并入 wave 分离存储）。
  时间戳仍复用 `tsPoints`（同一采样网格）。
- **固件待补**：`active_realtime_batch` 加 `i5`(detrended_ir) 或 `raw_ir`(±`avg_ir`)，
  长度与 `i6` 一致。已写进 `docs/ble-interface.md` 4.5.1 与「待确认事项」。
  未补之前首页「状态识别」会明确提示缺字段。
- 验证：node 桩 wx 跑通 5 个用例（60s 带时间戳 / 无时间戳回退 / 20s 报错 /
  空波形报错 / 无时间轴报错），三文件 `node --check` 全过。

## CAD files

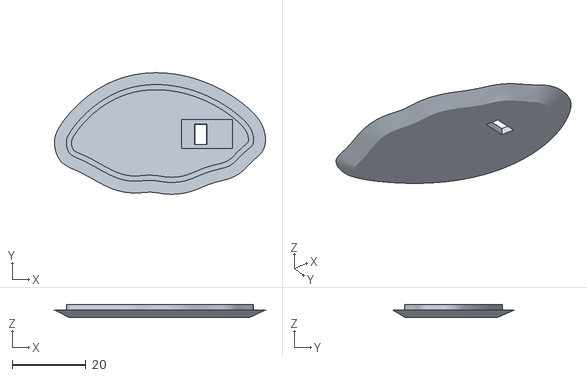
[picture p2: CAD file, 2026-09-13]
hardware/3D Printing/Shell Bottom.stl
57.0 x 32.9 x 3.50

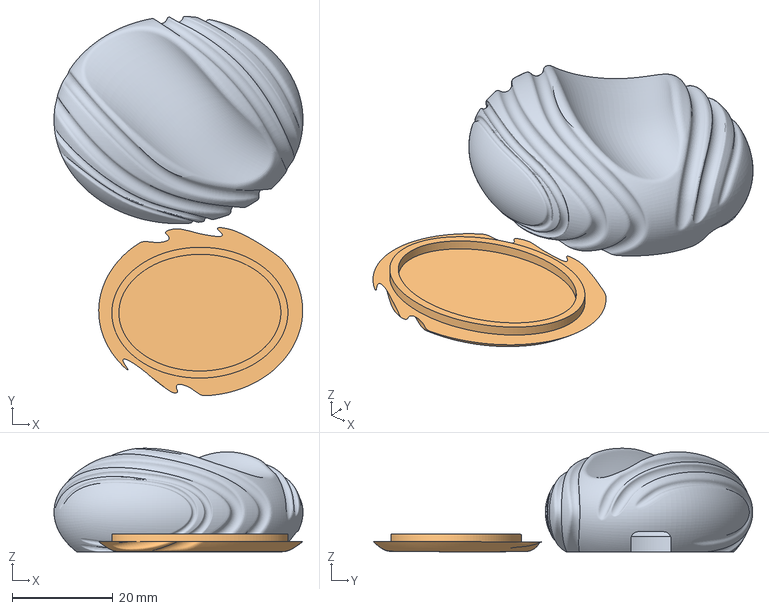
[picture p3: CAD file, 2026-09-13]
hardware/3D Printing/HOLD Egg.3mf
49.5 x 75.4 x 20.6 mm
HOLD A.stl
HOLD B.stl

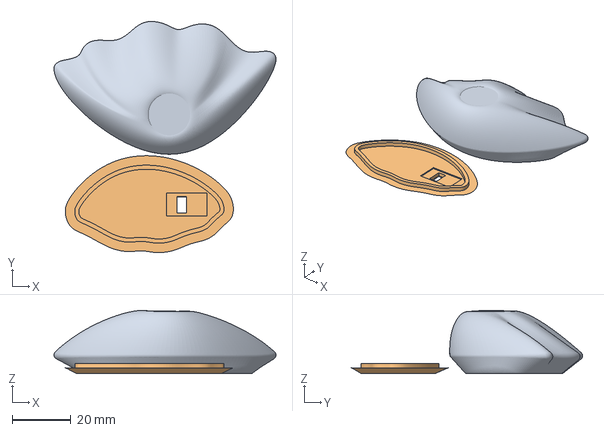
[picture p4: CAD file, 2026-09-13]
hardware/3D Printing/Shell.3mf
75.3 x 78.4 x 21.5 mm
Shell Top.stl
Shell Bottom.stl

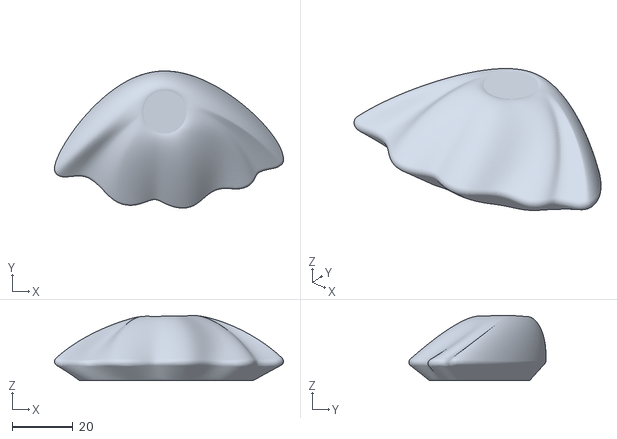
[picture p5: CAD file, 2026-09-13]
hardware/3D Printing/Shell Top.stl
75.3 x 45.1 x 21.5

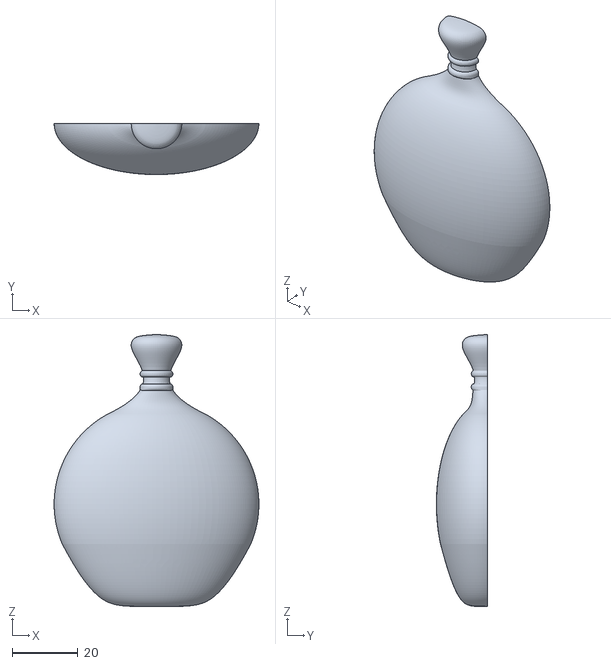
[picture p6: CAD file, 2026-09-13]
hardware/3D Printing/扁形瓶分件A.stl
62.5 x 15.6 x 83.0

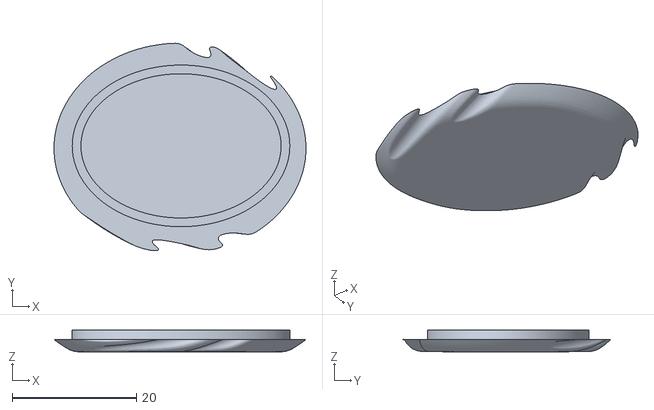
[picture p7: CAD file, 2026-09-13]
hardware/3D Printing/HOLD B.stl
40.5 x 33.4 x 3.50

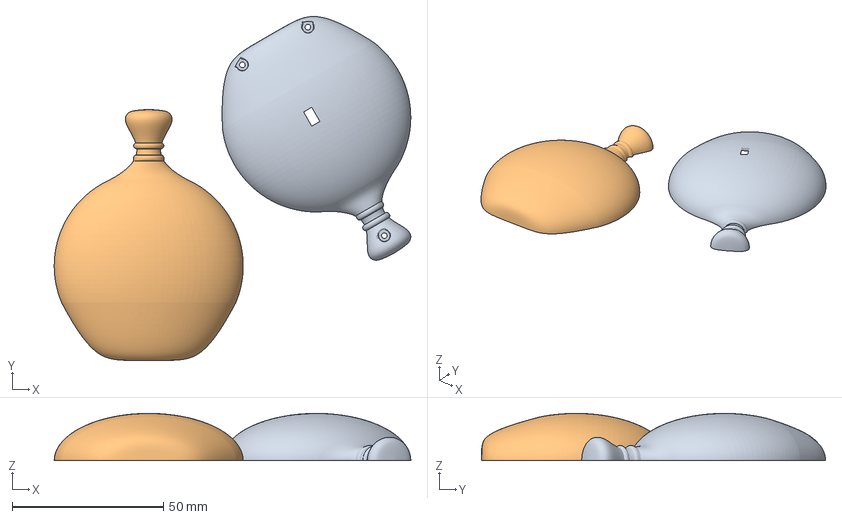
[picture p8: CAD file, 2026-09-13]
hardware/3D Printing/扁形瓶分件.3mf
117.9 x 113.7 x 15.6 mm
圆瓶嘴分件B.stl
圆瓶嘴分件A.stl

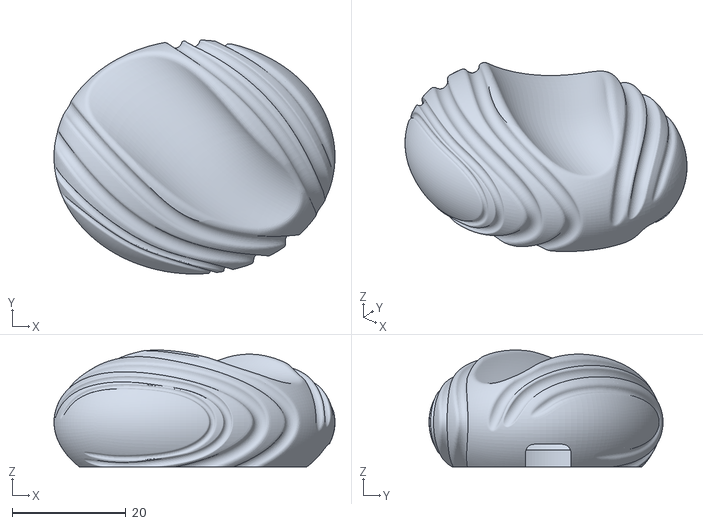
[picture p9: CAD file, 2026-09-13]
hardware/3D Printing/HOLD A.stl
49.5 x 41.2 x 20.6

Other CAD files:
hardware/3D Printing/扁形瓶分件B.stl

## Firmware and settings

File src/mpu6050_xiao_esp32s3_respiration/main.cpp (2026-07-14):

/*
 * 创建时间: 2026-06-08
 * 文件主要职责: 在 XIAO ESP32S3 / Plus + MPU6050 上实现“引导式个体化校准 + 个人参数运行”的单 IMU 呼吸实验入口。
 * 核心函数输入输出:
 * - setup(): 初始化串口、I2C 和 MPU6050，打印接线说明，并进入引导式校准流程。
 * - loop(): 固定采样读取 IMU；校准阶段按提示学习个人基线与叹气特征，运行阶段输出呼吸周期、吸气/呼气时间和叹气计数。
 * 最后更改时间: 2026-06-09
 * 累加式更改日志:
 * - 2026-06-08: 新建单 IMU 呼吸实验入口。
 * - 2026-06-08: 由固定阈值实验切换到“引导式个体化校准 + 轻量学习”第一版实现。
 * - 2026-06-09: 新增运行阶段 VOFA 调试输出，便于观察原始载波、基线与判定量曲线。
 * 注意事项:
 * - 当前版本不做复杂模型训练，而是根据校准阶段统计个人参数。
 * - 第一版默认每次上电重新校准，暂不写入 Flash 持久化。
 * - 当前目标是形成可验证的工程闭环，而不是医学级识别精度。
 */

#include <Arduino.h>
#include <Wire.h>

#include <math.h>

#include "project_config.h"

namespace {

constexpr uint32_t kSerialBaudRate = 115200;
constexpr uint8_t kMpu6050AddressLow = 0x68;
constexpr uint8_t kMpu6050AddressHigh = 0x69;
constexpr uint8_t kRegisterWhoAmI = 0x75;
constexpr uint8_t kRegisterPowerManagement1 = 0x6B;
constexpr uint8_t kRegisterAccelXoutH = 0x3B;
constexpr uint8_t kExpectedWhoAmI = 0x68;

constexpr unsigned long kStartupDelayMs = 300;
constexpr unsigned long kSampleIntervalMs = 20;
constexpr unsigned long kLogIntervalMs = 1000;
constexpr unsigned long kReconnectIntervalMs = 1000;
constexpr unsigned long kBreathDetectorWarmupMs = 3000;
constexpr unsigned long kMinExtremumGapMs = 250;
constexpr unsigned long kBreathDisplayStaleMs = 6000;

constexpr unsigned long kCalibrationStillMs = 10000;
constexpr unsigned long kNormalInhalePromptMs = 2000;
constexpr unsigned long kNormalExhalePromptMs = 3000;
constexpr uint8_t kNormalCycles = 6;
constexpr unsigned long kDeepInhalePromptMs = 3000;
constexpr unsigned long kDeepExhalePromptMs = 4000;
constexpr uint8_t kDeepCycles = 3;
constexpr unsigned long kSighInhalePromptMs = 2000;
constexpr unsigned long kSighExhalePromptMs = 6000;
constexpr uint8_t kSighCycles = 3;

constexpr unsigned long kDefaultMinHalfBreathMs = 560;
constexpr unsigned long kDefaultMinBreathIntervalMs = 1300;
constexpr unsigned long kDefaultMaxBreathIntervalMs = 10000;
constexpr unsigned long kAcceptanceLockMinMs = 900;
constexpr unsigned long kAcceptanceLockMaxMs = 2200;
constexpr float kAcceptanceLockRatio = 0.50f;

constexpr float kAccelLsbPerG = 16384.0f;
constexpr float kGyroLsbPerDps = 131.0f;
constexpr float kGravityEstimateAlpha = 0.02f;
constexpr float kBreathBaselineAlpha = 0.003f;
constexpr float kBreathSmoothAlpha = 0.18f;
constexpr float kBreathDetectionLowPassAlpha = 0.12f;
constexpr float kFallbackAmplitudeThresholdG = 0.0045f;

struct Mpu6050Sample {
  int16_t accelX = 0;
  int16_t accelY = 0;
  int16_t accelZ = 0;
  int16_t temperatureRaw = 0;
  int16_t gyroX = 0;
  int16_t gyroY = 0;
  int16_t gyroZ = 0;
};

struct Vector3f {
  float x = 0.0f;
  float y = 0.0f;
  float z = 0.0f;

  Vector3f() = default;
  Vector3f(float xValue, float yValue, float zValue)
      : x(xValue), y(yValue), z(zValue) {}
};

enum class MotionLevel {
  kStill,
  kLight,
  kVigorous,
};

enum class BreathRejectReason {
  kNone,
  kWarmup,
  kMotionGated,
  kPeakNeedTrough,
  kPeakHalfTooShort,
  kTroughNeedPeak,
  kTroughHalfTooShort,
  kIntervalOutOfRange,
  kAmplitudeTooLow,
};

enum class CalibrationStage {
  kStillBaseline,
  kNormalInhale,
  kNormalExhale,
  kDeepInhale,
  kDeepExhale,
  kSighInhale,
  kSighExhale,
  kRuntime,
};

struct BreathState {
  bool hasBreathInterval = false;
  float breathIntervalSeconds = 0.0f;
  bool hasBreathRate = false;
  float breathRateBpm = 0.0f;
  bool hasInhaleSeconds = false;
  float inhaleSeconds = 0.0f;
  bool hasExhaleSeconds = false;
  float exhaleSeconds = 0.0f;
  uint32_t sighCount = 0;
  float breathSignalG = 0.0f;
  float breathAmplitudeG = 0.0f;
  float averageBreathIntervalSeconds = 0.0f;
  float averageInhaleSeconds = 0.0f;
  float averageExhaleSeconds = 0.0f;
  float averageAmplitudeG = 0.0f;
};

struct AxisRangeAccumulator {
  bool initialized = false;
  float minValues[3] = {0.0f, 0.0f, 0.0f};
  float maxValues[3] = {0.0f, 0.0f, 0.0f};

  void observe(const Vector3f& sample) {
    const float values[3] = {sample.x, sample.y, sample.z};
    if (!initialized) {
      initialized = true;
      for (uint8_t index = 0; index < 3; ++index) {
        minValues[index] = values[index];
        maxValues[index] = values[index];
      }
      return;
    }

    for (uint8_t index = 0; index < 3; ++index) {
      if (values[index] < minValues[index]) {
        minValues[index] = values[index];
      }
      if (values[index] > maxValues[index]) {
        maxValues[index] = values[index];
      }
    }
  }

  float rangeForAxis(uint8_t axisIndex) const {
    if (!initialized || axisIndex > 2) {
      return 0.0f;
    }
    return maxValues[axisIndex] - minValues[axisIndex];
  }

  uint8_t dominantAxisIndex() const {
    float bestRange = -1.0f;
    uint8_t bestIndex = 2;
    for (uint8_t index = 0; index < 3; ++index) {
      const float currentRange = rangeForAxis(index);
      if (currentRange > bestRange) {
        bestRange = currentRange;
        bestIndex = index;
      }
    }
    return bestIndex;
  }
};

struct MotionAccumulator {
  uint32_t sampleCount = 0;
  float gyroSum = 0.0f;
  float gyroMax = 0.0f;
  float dynamicAccelSum = 0.0f;
  float dynamicAccelMax = 0.0f;

  void observe(float gyroNormDps, float dynamicAccelNormG) {
    ++sampleCount;
    gyroSum += gyroNormDps;
    dynamicAccelSum += dynamicAccelNormG;
    if (gyroNormDps > gyroMax) {
      gyroMax = gyroNormDps;
    }
    if (dynamicAccelNormG > dynamicAccelMax) {
      dynamicAccelMax = dynamicAccelNormG;
    }
  }

  float gyroMean() const {
    return sampleCount == 0 ? 0.0f : gyroSum / static_cast<float>(sampleCount);
  }

  float dynamicAccelMean() const {
    return sampleCount == 0 ? 0.0f : dynamicAccelSum / static_cast<float>(sampleCount);
  }
};

struct SignalAccumulator {
  uint32_t sampleCount = 0;
  float signedSum = 0.0f;
  float absoluteSum = 0.0f;
  float minValue = 0.0f;
  float maxValue = 0.0f;
  bool initialized = false;

  void observe(float value) {
    ++sampleCount;
    signedSum += value;
    absoluteSum += fabsf(value);

    if (!initialized) {
      initialized = true;
      minValue = value;
      maxValue = value;
      return;
    }

    if (value < minValue) {
      minValue = value;
    }
    if (value > maxValue) {
      maxValue = value;
    }
  }

  float mean() const {
    return sampleCount == 0 ? 0.0f : signedSum / static_cast<float>(sampleCount);
  }

  float meanAbsolute() const {
    return sampleCount == 0 ? 0.0f : absoluteSum / static_cast<float>(sampleCount);
  }

  float peakToPeak() const {
    return initialized ? maxValue - minValue : 0.0f;
  }
};

struct PersonalProfile {
  bool ready = false;
  uint8_t lockedAxisIndex = 2;
  char lockedAxis = 'z';
  float normalAmplitudeG = 0.0f;
  float deepAmplitudeG = 0.0f;
  float sighAmplitudeG = 0.0f;
  float normalPhaseDeltaG = 0.0f;
  float deepPhaseDeltaG = 0.0f;
  float sighPhaseDeltaG = 0.0f;
  float amplitudeThresholdG = kFallbackAmplitudeThresholdG;
  float stillGyroThresholdDps = 12.0f;
  float lightGyroThresholdDps = 35.0f;
  float vigorousGyroThresholdDps = 120.0f;
  float stillDynamicAccelThresholdG = 0.015f;
  float lightDynamicAccelThresholdG = 0.08f;
  float vigorousDynamicAccelThresholdG = 0.22f;
  unsigned long minHalfBreathMs = kDefaultMinHalfBreathMs;
  unsigned long minBreathIntervalMs = kDefaultMinBreathIntervalMs;
  unsigned long maxBreathIntervalMs = kDefaultMaxBreathIntervalMs;
  unsigned long expectedNormalIntervalMs = kNormalInhalePromptMs + kNormalExhalePromptMs;
  unsigned long expectedInhaleMs = kNormalInhalePromptMs;
  unsigned long expectedExhaleMs = kNormalExhalePromptMs;
  unsigned long sighExhaleThresholdMs = 4500;
  unsigned long sighIntervalThresholdMs = 6500;
  float sighAmplitudeThresholdG = 0.02f;
  float acceptanceLockRatio = kAcceptanceLockRatio;
};

struct RuntimeState {
  bool sensorReady = false;
  bool runtimeLogPaused = true;
  uint8_t activeAddress = 0;
  unsigned long startedAtMs = 0;
  unsigned long lastSampleAtMs = 0;
  unsigned long lastReconnectAtMs = 0;
  unsigned long lastLogAtMs = 0;
  uint32_t sampleIndex = 0;
  Vector3f gravityEstimateG = Vector3f(0.0f, 0.0f, 1.0f);

  CalibrationStage calibrationStage = CalibrationStage::kStillBaseline;
  unsigned long calibrationStageStartedAtMs = 0;
  bool calibrationPromptPrinted = false;
  uint8_t normalCycleIndex = 0;
  uint8_t deepCycleIndex = 0;
  uint8_t sighCycleIndex = 0;
  MotionAccumulator stillMotionStats;
  AxisRangeAccumulator normalAxisStats;
  AxisRangeAccumulator deepAxisStats;
  AxisRangeAccumulator sighAxisStats;
  AxisRangeAccumulator combinedAxisStats;
  SignalAccumulator normalSignalStats;
  SignalAccumulator normalInhaleSignalStats;
  SignalAccumulator normalExhaleSignalStats;
  SignalAccumulator deepSignalStats;
  SignalAccumulator deepInhaleSignalStats;
  SignalAccumulator deepExhaleSignalStats;
  SignalAccumulator sighSignalStats;
  SignalAccumulator sighInhaleSignalStats;
  SignalAccumulator sighExhaleSignalStats;
  PersonalProfile profile;

  float breathBaselineG = 0.0f;
  float breathFilteredG = 0.0f;
  float breathDetectionFilteredG = 0.0f;
  float previousBreathDetectionFilteredG = 0.0f;
  float previousBreathFilteredG = 0.0f;
  float previousBreathSlope = 0.0f;
  bool detectorPrimed = false;
  MotionLevel motionLevel = MotionLevel::kStill;
  float accelNormG = 1.0f;
  float dynamicAccelNormG = 0.0f;
  float gyroNormDps = 0.0f;
  float pitchDeg = 0.0f;
  float rollDeg = 0.0f;
  float breathCarrierG = 0.0f;
  float breathDetrendedG = 0.0f;
  float currentBreathSlopeG = 0.0f;
  unsigned long lastPeakAtMs = 0;
  unsigned long lastTroughAtMs = 0;
  float lastPeakValueG = 0.0f;
  float lastTroughValueG = 0.0f;
  bool hasPeak = false;
  bool hasTrough = false;
  float averageBreathIntervalMs = 0.0f;
  float averageInhaleMs = 0.0f;
  float averageExhaleMs = 0.0f;
  float averageAmplitudeG = 0.0f;
  float latestBreathIntervalMs = 0.0f;
  float latestInhaleMs = 0.0f;
  float latestExhaleMs = 0.0f;
  float latestAmplitudeG = 0.0f;
  uint32_t averagedBreathCount = 0;
  uint32_t sighCount = 0;
  unsigned long lastSighAtMs = 0;
  uint32_t detectedPeakCount = 0;
  uint32_t detectedTroughCount = 0;
  uint32_t acceptedCycleCount = 0;
  unsigned long lastAcceptedCycleAtMs = 0;
  BreathRejectReason lastRejectReason = BreathRejectReason::kNone;
  unsigned long lastRejectDurationMs = 0;
  float lastRejectAmplitudeG = 0.0f;
};

RuntimeState runtimeState;

float squaref(float value) {
  return value * value;
}

float vectorNorm(const Vector3f& value) {
  return sqrtf(squaref(value.x) + squaref(value.y) + squaref(value.z));
}

Vector3f normalizeVector(const Vector3f& value) {
  const float norm = vectorNorm(value);
  if (norm <= 0.0001f) {
    return Vector3f(0.0f, 0.0f, 1.0f);
  }
  return Vector3f(value.x / norm, value.y / norm, value.z / norm);
}

float maxFloat(float left, float right) {
  return left > right ? left : right;
}

float minFloat(float left, float right) {
  return left < right ? left : right;
}

float boolToFloat(bool value) {
  return value ? 1.0f : 0.0f;
}

float maxFloat3(float first, float second, float third) {
  return maxFloat(maxFloat(first, second), third);
}

unsigned long maxUnsignedLong(unsigned long left, unsigned long right) {
  return left > right ? left : right;
}

unsigned long clampUnsignedLong(unsigned long value, unsigned long minValue, unsigned long maxValue) {
  if (value < minValue) {
    return minValue;
  }
  if (value > maxValue) {
    return maxValue;
  }
  return value;
}

float updateAverage(float previousAverage, uint32_t sampleCount, float value) {
  if (sampleCount == 0) {
    return value;
  }
  return previousAverage + (value - previousAverage) / static_cast<float>(sampleCount + 1);
}

float computeExtremumConfirmDeltaG() {
  return maxFloat(0.0035f, runtimeState.profile.amplitudeThresholdG * 0.45f);
}

char axisChar(uint8_t axisIndex) {
  switch (axisIndex) {
    case 0:
      return 'x';
    case 1:
      return 'y';
    default:
      return 'z';
  }
}

float axisValue(const Vector3f& value, uint8_t axisIndex) {
  switch (axisIndex) {
    case 0:
      return value.x;
    case 1:
      return value.y;
    default:
      return value.z;
  }
}

float convertTemperatureCelsius(int16_t rawTemperature) {
  return static_cast<float>(rawTemperature) / 340.0f + 36.53f;
}

float convertAccelToG(int16_t rawAcceleration) {
  return static_cast<float>(rawAcceleration) / kAccelLsbPerG;
}

float convertGyroToDps(int16_t rawGyro) {
  return static_cast<float>(rawGyro) / kGyroLsbPerDps;
}

const char* motionLevelToText(MotionLevel level) {
  switch (level) {
    case MotionLevel::kStill:
      return "still";
    case MotionLevel::kLight:
      return "light";
    case MotionLevel::kVigorous:
      return "vigorous";
  }
  return "unknown";
}

const char* rejectReasonToText(BreathRejectReason reason) {
  switch (reason) {
    case BreathRejectReason::kNone:
      return "none";
    case BreathRejectReason::kWarmup:
      return "warmup";
    case BreathRejectReason::kMotionGated:
      return "motion_gated";
    case BreathRejectReason::kPeakNeedTrough:
      return "peak_need_trough";
    case BreathRejectReason::kPeakHalfTooShort:
      return "peak_half_short";
    case BreathRejectReason::kTroughNeedPeak:
      return "trough_need_peak";
    case BreathRejectReason::kTroughHalfTooShort:
      return "trough_half_short";
    case BreathRejectReason::kIntervalOutOfRange:
      return "interval_out_of_range";
    case BreathRejectReason::kAmplitudeTooLow:
      return "amplitude_too_low";
  }
  return "unknown";
}

uint8_t motionLevelToCode(MotionLevel level) {
  switch (level) {
    case MotionLevel::kStill:
      return 0;
    case MotionLevel::kLight:
      return 1;
    case MotionLevel::kVigorous:
      return 2;
  }
  return 255;
}

uint8_t rejectReasonToCode(BreathRejectReason reason) {
  switch (reason) {
    case BreathRejectReason::kNone:
      return 0;
    case BreathRejectReason::kWarmup:
      return 1;
    case BreathRejectReason::kMotionGated:
      return 2;
    case BreathRejectReason::kPeakNeedTrough:
      return 3;
    case BreathRejectReason::kPeakHalfTooShort:
      return 4;
    case BreathRejectReason::kTroughNeedPeak:
      return 5;
    case BreathRejectReason::kTroughHalfTooShort:
      return 6;
    case BreathRejectReason::kIntervalOutOfRange:
      return 7;
    case BreathRejectReason::kAmplitudeTooLow:
      return 8;
  }
  return 255;
}

const char* calibrationStageToText(CalibrationStage stage) {
  switch (stage) {
    case CalibrationStage::kStillBaseline:
      return "静止基线";
    case CalibrationStage::kNormalInhale:
      return "正常呼吸-吸气";
    case CalibrationStage::kNormalExhale:
      return "正常呼吸-呼气";
    case CalibrationStage::kDeepInhale:
      return "深呼吸-吸气";
    case CalibrationStage::kDeepExhale:
      return "深呼吸-呼气";
    case CalibrationStage::kSighInhale:
      return "叹气-吸气";
    case CalibrationStage::kSighExhale:
      return "叹气-长呼气";
    case CalibrationStage::kRuntime:
      return "运行模式";
  }
  return "未知阶段";
}

unsigned long stageDurationMs(CalibrationStage stage) {
  switch (stage) {
    case CalibrationStage::kStillBaseline:
      return kCalibrationStillMs;
    case CalibrationStage::kNormalInhale:
      return kNormalInhalePromptMs;
    case CalibrationStage::kNormalExhale:
      return kNormalExhalePromptMs;
    case CalibrationStage::kDeepInhale:
      return kDeepInhalePromptMs;
    case CalibrationStage::kDeepExhale:
      return kDeepExhalePromptMs;
    case CalibrationStage::kSighInhale:
      return kSighInhalePromptMs;
    case CalibrationStage::kSighExhale:
      return kSighExhalePromptMs;
    case CalibrationStage::kRuntime:
      return 0;
  }
  return 0;
}

unsigned long computeAcceptanceLockMs() {
  float referenceIntervalMs = runtimeState.latestBreathIntervalMs;
  if (referenceIntervalMs <= 0.0f) {
    referenceIntervalMs = runtimeState.averageBreathIntervalMs;
  }
  if (referenceIntervalMs <= 0.0f) {
    referenceIntervalMs = static_cast<float>(runtimeState.profile.expectedNormalIntervalMs);
  }

  return clampUnsignedLong(
      static_cast<unsigned long>(referenceIntervalMs * runtimeState.profile.acceptanceLockRatio),
      kAcceptanceLockMinMs,
      kAcceptanceLockMaxMs);
}

void logWiringGuide() {
  Serial.println("[wiring] XIAO 3V3 -> MPU6050 VCC");
  Serial.println("[wiring] XIAO GND -> MPU6050 GND");
  Serial.println("[wiring] XIAO D4(GPIO5/SDA) -> MPU6050 SDA");
  Serial.println("[wiring] XIAO D5(GPIO6/SCL) -> MPU6050 SCL");
  Serial.println("[wiring] MPU6050 AD0/ADC -> GND (默认地址 0x68)");
  Serial.println("[wiring] MPU6050 INT/XDA/XCL 本阶段先不接");
}

bool probeAddress(uint8_t address) {
  Wire.beginTransmission(address);
  return Wire.endTransmission() == 0;
}

bool readRegister(uint8_t address, uint8_t reg, uint8_t& value) {
  Wire.beginTransmission(address);
  Wire.write(reg);
  if (Wire.endTransmission(false) != 0) {
    return false;
  }

  const uint8_t bytesRead = Wire.requestFrom(address, static_cast<uint8_t>(1), static_cast<uint8_t>(true));
  if (bytesRead != 1) {
    return false;
  }

  value = Wire.read();
  return true;
}

bool writeRegister(uint8_t address, uint8_t reg, uint8_t value) {
  Wire.beginTransmission(address);
  Wire.write(reg);
  Wire.write(value);
  return Wire.endTransmission() == 0;
}

bool readSample(uint8_t address, Mpu6050Sample& sample) {
  Wire.beginTransmission(address);
  Wire.write(kRegisterAccelXoutH);
  if (Wire.endTransmission(false) != 0) {
    return false;
  }

  const uint8_t bytesRequested = 14;
  const uint8_t bytesRead = Wire.requestFrom(address, bytesRequested, static_cast<uint8_t>(true));
  if (bytesRead != bytesRequested) {
    return false;
  }

  sample.accelX = static_cast<int16_t>((Wire.read() << 8) | Wire.read());
  sample.accelY = static_cast<int16_t>((Wire.read() << 8) | Wire.read());
  sample.accelZ = static_cast<int16_t>((Wire.read() << 8) | Wire.read());
  sample.temperatureRaw = static_cast<int16_t>((Wire.read() << 8) | Wire.read());
  sample.gyroX = static_cast<int16_t>((Wire.read() << 8) | Wire.read());
  sample.gyroY = static_cast<int16_t>((Wire.read() << 8) | Wire.read());
  sample.gyroZ = static_cast<int16_t>((Wire.read() << 8) | Wire.read());
  return true;
}

void resetRuntimeDetectorState() {
  runtimeState.runtimeLogPaused = true;
  runtimeState.breathBaselineG = 0.0f;
  runtimeState.breathFilteredG = 0.0f;
  runtimeState.breathDetectionFilteredG = 0.0f;
  runtimeState.previousBreathDetectionFilteredG = 0.0f;
  runtimeState.breathDetrendedG = 0.0f;
  runtimeState.currentBreathSlopeG = 0.0f;
  runtimeState.previousBreathFilteredG = 0.0f;
  runtimeState.previousBreathSlope = 0.0f;
  runtimeState.detectorPrimed = false;
  runtimeState.lastPeakAtMs = 0;
  runtimeState.lastTroughAtMs = 0;
  runtimeState.lastPeakValueG = 0.0f;
  runtimeState.lastTroughValueG = 0.0f;
  runtimeState.hasPeak = false;
  runtimeState.hasTrough = false;
  runtimeState.averageBreathIntervalMs = 0.0f;
  runtimeState.averageInhaleMs = 0.0f;
  runtimeState.averageExhaleMs = 0.0f;
  runtimeState.averageAmplitudeG = 0.0f;
  runtimeState.latestBreathIntervalMs = 0.0f;
  runtimeState.latestInhaleMs = 0.0f;
  runtimeState.latestExhaleMs = 0.0f;
  runtimeState.latestAmplitudeG = 0.0f;
  runtimeState.averagedBreathCount = 0;
  runtimeState.sighCount = 0;
  runtimeState.lastSighAtMs = 0;
  runtimeState.detectedPeakCount = 0;
  runtimeState.detectedTroughCount = 0;
  runtimeState.acceptedCycleCount = 0;
  runtimeState.lastAcceptedCycleAtMs = 0;
  runtimeState.lastRejectReason = BreathRejectReason::kNone;
  runtimeState.lastRejectDurationMs = 0;
  runtimeState.lastRejectAmplitudeG = 0.0f;
}
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
void loop() {
  const unsigned long nowMs = millis();

  if (!runtimeState.sensorReady) {
    if (nowMs - runtimeState.lastReconnectAtMs < kReconnectIntervalMs) {
      return;
    }

    runtimeState.lastReconnectAtMs = nowMs;
    tryInitializeSensor();
    return;
  }

  if (nowMs - runtimeState.lastSampleAtMs < kSampleIntervalMs) {
    return;
  }
  runtimeState.lastSampleAtMs = nowMs;

  Mpu6050Sample sample;
  if (!readSample(runtimeState.activeAddress, sample)) {
    Serial.println("[mpu6050-cal] sample read failed, sensor will be re-probed");
    runtimeState.sensorReady = false;
    return;
  }

  updateMotionAndSignal(nowMs, sample);
  if (runtimeState.calibrationStage != CalibrationStage::kRuntime) {
    updateCalibration(nowMs);
  }

  if (runtimeState.calibrationStage != CalibrationStage::kRuntime) {
    return;
  }

  if (project_config::kEnableMpu6050RespirationVofaStream) {
    if (nowMs - runtimeState.lastLogAtMs < project_config::kMpu6050RespirationVofaStreamIntervalMs) {
      return;
    }
    runtimeState.lastLogAtMs = nowMs;
    printRuntimeVofaFrame(nowMs, sample);
    return;
  }

  if (runtimeState.runtimeLogPaused) {
    return;
  }

  if (nowMs - runtimeState.lastLogAtMs < kLogIntervalMs) {
    return;
  }
  runtimeState.lastLogAtMs = nowMs;
  printRuntimeStatus(nowMs, sample, buildBreathState(nowMs));
}

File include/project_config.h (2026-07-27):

/*
 * 创建时间: 2026-05-22
 * 文件主要职责: 集中管理 XIAO ESP32S3 当前工程的板级参数、MAX30102 验证参数与 ICS43434 麦克风参数。
 * 核心函数输入输出: 本文件仅提供常量定义，供主程序和传感器模块读取引脚、节拍、地址与采样配置。
 * 最后更改时间: 2026-06-09
 * 累加式更改日志:
 * - 2026-05-22: 新建板级配置头文件，定义板载用户灯引脚和闪烁周期。
 * - 2026-05-22: 随 PlatformIO 工程一起移动到 HOLD 根目录。
 * - 2026-05-23: 补充 MAX30102 原始数据读取所需的 I2C 引脚、地址与日志节拍配置。
 * - 2026-05-25: 补充 ICS43434 麦克风 I2S 引脚、采样率、批处理与日志节拍配置。
 * - 2026-06-09: 补充单 IMU 呼吸实验的 VOFA 调试开关与输出节拍配置。
 * 注意事项:
 * - XIAO ESP32S3 系列板载用户灯为低电平点亮。
 * - 当前 I2C 引脚按 Seeed 官方 XIAO ESP32S3 默认功能使用 D4(GPIO5)/D5(GPIO6)。
 */

#pragma once

#include <Arduino.h>

namespace project_config {

constexpr uint8_t kUserLedPin = 21;
constexpr uint8_t kLedOnLevel = LOW;
constexpr uint8_t kLedOffLevel = HIGH;
constexpr unsigned long kBlinkIntervalMs = 250;
constexpr unsigned long kSerialReadyTimeoutMs = 2000;

constexpr uint8_t kI2cSdaPin = 5;
constexpr uint8_t kI2cSclPin = 6;
constexpr uint32_t kI2cClockHz = 100000;
constexpr uint8_t kMax30102Address = 0x57;
constexpr uint8_t kExpectedMax30102PartId = 0x15;

constexpr uint16_t kSensorAdcSampleRateHz = 100;
constexpr uint8_t kFifoSampleAverage = 4;
constexpr uint16_t kSensorEffectiveSampleRateHz =
	kSensorAdcSampleRateHz / kFifoSampleAverage;
constexpr unsigned long kSensorPollIntervalMs = 10;
constexpr unsigned long kHeartRateLogIntervalMs = 500;
constexpr bool kEnableHeartRateStatusLog = false;
constexpr bool kEnableMax30102VofaStream = true;
constexpr unsigned long kMax30102VofaStreamIntervalMs = kSensorPollIntervalMs;
constexpr float kMax30102VofaFilteredDisplayGain = 4.0f;
constexpr unsigned long kStartupDelayMs = 300;

constexpr int8_t kMicrophoneBclkPin = 7;
constexpr int8_t kMicrophoneWsPin = 8;
constexpr int8_t kMicrophoneDataPin = 9;
constexpr uint32_t kMicrophoneSampleRateHz = 16000;
constexpr size_t kMicrophoneBatchSampleCount = 160;
constexpr size_t kMicrophoneDmaBufferCount = 4;
constexpr size_t kMicrophoneDmaBufferLength = 256;
constexpr unsigned long kMicrophonePollIntervalMs = kSensorPollIntervalMs;
constexpr unsigned long kMicrophoneLogIntervalMs = kHeartRateLogIntervalMs;

constexpr uint8_t kPressureAdcPin = 1;
constexpr uint8_t kPressureAdcResolutionBits = 12;
constexpr size_t kPressureBaselineSampleCount = 32;
constexpr size_t kPressureAverageSampleCount = 8;
constexpr uint16_t kPressureMinimumRangeRaw = 300;
constexpr unsigned long kPressurePollIntervalMs = kSensorPollIntervalMs;
constexpr unsigned long kPressureLogIntervalMs = kHeartRateLogIntervalMs;

constexpr uint8_t kAd8232AdcPin = 2;
constexpr uint8_t kAd8232AdcResolutionBits = 12;
constexpr unsigned long kAd8232PollIntervalMs = 4;
constexpr unsigned long kAd8232LogIntervalMs = 100;
constexpr bool kEnableAd8232VofaStream = false;
constexpr unsigned long kAd8232VofaStreamIntervalMs = kAd8232PollIntervalMs;

constexpr bool kEnableMpu6050RespirationVofaStream = true;
constexpr unsigned long kMpu6050RespirationVofaStreamIntervalMs = 20;

constexpr uint32_t kFingerPresentIrMeanThreshold = 8000;
constexpr uint32_t kFingerPresentRedMeanThreshold = 2000;
constexpr uint8_t kMax30102LedRedPulseAmplitude = 0x3C;
constexpr uint8_t kMax30102LedIrPulseAmplitude = 0x3C;
constexpr float kHeartRateDcAlpha = 0.05f;
constexpr float kHeartRateSignalAlpha = 0.20f;
constexpr float kHeartRateAmplitudeMin = 80.0f;
constexpr unsigned long kHeartRateBeatIntervalMinMs = 400;
constexpr unsigned long kHeartRateBeatIntervalMaxMs = 1500;
constexpr unsigned long kHeartRateBeatStaleTimeoutMs = 5000;
constexpr unsigned long kHeartRateFingerLossResetMs = 3000;

}  // namespace project_config

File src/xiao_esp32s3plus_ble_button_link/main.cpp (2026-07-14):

#include <Arduino.h>
#include <BLE2902.h>
#include <BLEDevice.h>
#include <BLEServer.h>
#include <BLEUtils.h>
#include <Wire.h>

#include <Adafruit_DRV2605.h>

namespace {
constexpr char kDeviceName[] = "HOLD-LINK-TEST";
constexpr char kServiceUuid[] = "19B10010-E8F2-537E-4F6C-D104768A1214";
constexpr char kEventUuid[] = "19B10011-E8F2-537E-4F6C-D104768A1214";
constexpr char kInfoUuid[] = "19B10012-E8F2-537E-4F6C-D104768A1214";
constexpr char kCommandUuid[] = "19B10013-E8F2-537E-4F6C-D104768A1214";

constexpr uint8_t kButtonPin = 0;
constexpr uint8_t kUserLedPin = 21;
constexpr uint32_t kDebounceMs = 180;
constexpr uint32_t kTelemetryMs = 1000;
constexpr uint32_t kBreathStepMs = 120;
constexpr uint32_t kCalibrationMs = 12000;

BLECharacteristic* eventCharacteristic = nullptr;
BLECharacteristic* commandCharacteristic = nullptr;
Adafruit_DRV2605 haptic;

bool isClientConnected = false;
bool hapticReady = false;
bool breathEnabled = false;
bool calibrationRunning = false;
bool lastStableButtonState = HIGH;
bool lastRawButtonState = HIGH;
uint32_t pressCount = 0;
uint32_t breathStep = 0;
uint32_t calibrationStartedAtMs = 0;
uint32_t lastDebounceAtMs = 0;
uint32_t lastAdvertiseLogAtMs = 0;
uint32_t lastTelemetryAtMs = 0;
uint32_t lastBreathStepAtMs = 0;

String jsonPair(const char* key, const String& value) {
  return "\"" + String(key) + "\":\"" + value + "\"";
}

void notifyJson(const String& payload) {
  Serial.println("[BLE] " + payload);
  if (eventCharacteristic != nullptr && isClientConnected) {
    eventCharacteristic->setValue(payload.c_str());
    eventCharacteristic->notify();
  }
}

void setMotor(uint8_t rtp) {
  if (hapticReady) {
    haptic.setRealtimeValue(rtp);
  }
  digitalWrite(kUserLedPin, rtp > 0 ? LOW : HIGH);
}

void stopFeedback() {
  breathEnabled = false;
  calibrationRunning = false;
  setMotor(0);
}

String buildStatusJson(const char* eventType) {
  String payload = "{";
  payload += jsonPair("event_type", eventType) + ",";
  payload += jsonPair("device_id", kDeviceName) + ",";
  payload += "\"press_count\":";
  payload += String(pressCount);
  payload += ",\"breath_enabled\":";
  payload += breathEnabled ? "true" : "false";
  payload += ",\"calibration_running\":";
  payload += calibrationRunning ? "true" : "false";
  payload += ",\"haptic_ready\":";
  payload += hapticReady ? "true" : "false";
  payload += ",\"device_timestamp\":";
  payload += String(millis());
  payload += "}";
  return payload;
}

void emitStatus(const char* eventType) {
  notifyJson(buildStatusJson(eventType));
}

void handleCommand(const String& command) {
  if (command.indexOf("breath_start") >= 0) {
    calibrationRunning = false;
    breathEnabled = true;
    breathStep = 0;
    lastBreathStepAtMs = 0;
    emitStatus("breath_started");
    return;
  }

  if (command.indexOf("breath_stop") >= 0) {
    stopFeedback();
    emitStatus("breath_stopped");
    return;
  }

  if (command.indexOf("calibrate_start") >= 0) {
    breathEnabled = false;
    calibrationRunning = true;
    calibrationStartedAtMs = millis();
    emitStatus("calibration_started");
    return;
  }

  emitStatus("unknown_command");
}

class CommandCallbacks final : public BLECharacteristicCallbacks {
 public:
  void onWrite(BLECharacteristic* characteristic) override {
    String command = characteristic->getValue().c_str();
    command.trim();
    Serial.println("[CMD] " + command);
    handleCommand(command);
  }
};

class LinkServerCallbacks final : public BLEServerCallbacks {
 public:
  void onConnect(BLEServer*) override {
    isClientConnected = true;
    Serial.println("[BLE] client connected");
    digitalWrite(kUserLedPin, LOW);
  }

  void onDisconnect(BLEServer*) override {
    isClientConnected = false;
    stopFeedback();
    Serial.println("[BLE] client disconnected, restart advertising");
    BLEDevice::startAdvertising();
  }
};

void setupHaptic() {
  Wire.begin();
  hapticReady = haptic.begin(&Wire);
  if (!hapticReady) {
    Serial.println("[HAPTIC] DRV2605L not found, using LED fallback");
    return;
  }

  haptic.useLRA();
  haptic.selectLibrary(6);
  haptic.setMode(DRV2605_MODE_REALTIME);
  haptic.setRealtimeValue(0);
  Serial.println("[HAPTIC] ready");
}

void setupBle() {
  BLEDevice::init(kDeviceName);
  BLEServer* server = BLEDevice::createServer();
  server->setCallbacks(new LinkServerCallbacks());

  BLEService* service = server->createService(kServiceUuid);
  eventCharacteristic = service->createCharacteristic(kEventUuid, BLECharacteristic::PROPERTY_NOTIFY);
  eventCharacteristic->addDescriptor(new BLE2902());

  service->createCharacteristic(kInfoUuid, BLECharacteristic::PROPERTY_READ)
      ->setValue(buildStatusJson("device_info").c_str());

  commandCharacteristic = service->createCharacteristic(kCommandUuid, BLECharacteristic::PROPERTY_WRITE);
  commandCharacteristic->setCallbacks(new CommandCallbacks());

  service->start();
  BLEAdvertising* advertising = BLEDevice::getAdvertising();
  advertising->addServiceUUID(service->getUUID());
  advertising->setScanResponse(true);
  BLEDevice::startAdvertising();
  Serial.println("[BLE] advertising started");
}

void updateBreathFeedback(uint32_t now) {
  if (!breathEnabled || now - lastBreathStepAtMs < kBreathStepMs) {
    return;
  }

  lastBreathStepAtMs = now;
  const uint8_t phase = breathStep++ % 40;
  const uint8_t rtp = phase < 20 ? phase * 4 : (39 - phase) * 4;
  setMotor(rtp);
}

void updateCalibration(uint32_t now) {
  if (!calibrationRunning) {
    return;
  }

  setMotor((now / 250) % 2 == 0 ? 0x35 : 0x00);
  if (now - calibrationStartedAtMs >= kCalibrationMs) {
    stopFeedback();
    emitStatus("calibration_done");
  }
}

void emitButtonEvent() {
  ++pressCount;
  emitStatus("button_press");
}
}  // namespace

void setup() {
  Serial.begin(115200);
  delay(800);
  pinMode(kButtonPin, INPUT_PULLUP);
  pinMode(kUserLedPin, OUTPUT);
  digitalWrite(kUserLedPin, HIGH);

  Serial.println("[BOOT] HOLD BLE link starting");
  setupHaptic();
  setupBle();
}

void loop() {
  const uint32_t now = millis();
  const bool rawState = digitalRead(kButtonPin);

  if (rawState != lastRawButtonState) {
    lastDebounceAtMs = now;
    lastRawButtonState = rawState;
  }

  if ((now - lastDebounceAtMs) > kDebounceMs && rawState != lastStableButtonState) {
    lastStableButtonState = rawState;
    if (lastStableButtonState == LOW) {
      emitButtonEvent();
    }
  }

  updateBreathFeedback(now);
  updateCalibration(now);

  if (isClientConnected && now - lastTelemetryAtMs > kTelemetryMs) {
    lastTelemetryAtMs = now;
    emitStatus("telemetry");
  }

  if (!isClientConnected && now - lastAdvertiseLogAtMs > 5000) {
    lastAdvertiseLogAtMs = now;
    Serial.println("[BLE] waiting for mini program connection...");
  }

  delay(10);
}

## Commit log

2026-07-14 Baseline from initial backup
    [max30102_chest_vofa.csv, max30102_finger_vofa.csv, temp_diff.txt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]
2026-07-14 Fix Android BLE scan flow and button layout
2026-07-15 Buffer fragmented BLE notifications and contain buttons
2026-07-15 Keep BLE connection and show calibration signal gaps
2026-07-15 Fix BLE notify fragmentation for calibration data
    [main.cpp]
2026-07-15 Restore live sensor telemetry and I2C diagnostics
2026-07-15 Stream live sensor waveforms over BLE
2026-07-21 Fix calibration completion and diagnostics
    [main.cpp]
2026-07-24 Move finger PPG trigger to pressure hold
2026-07-24 Stabilize PPG and pressure-triggered capture
    [main.cpp, project_config.h]
2026-07-27 Stabilize heart and breath detection
    [main.cpp, project_config.h]
2026-09-13 3D结构 打印文件
    [HOLD A.stl, HOLD B.stl, HOLD Egg.3mf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]
2026-09-14 新增用户系统；新增云存储；新增压力等级功能接入
2026-09-15 同步当前可用代码与界面设计
    [captures\max30102_chest\20260623_143842\max30102_chest_vofa.csv, captures\max30102_finger\20260623_153735\max30102_finger_vofa.csv, ref\MyApplication\app\src\m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]
2026-09-15 修正 GitHub 上传路径
    [captures\max30102_chest\20260623_143842\max30102_chest_vofa.csv, captures\max30102_finger\20260623_153735\max30102_finger_vofa.csv, ref\MyApplication\app\src\m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]
